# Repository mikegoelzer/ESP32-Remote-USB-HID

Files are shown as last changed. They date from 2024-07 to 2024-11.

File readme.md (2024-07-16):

# USB HID Keyboard over Wifi

<p align="center">
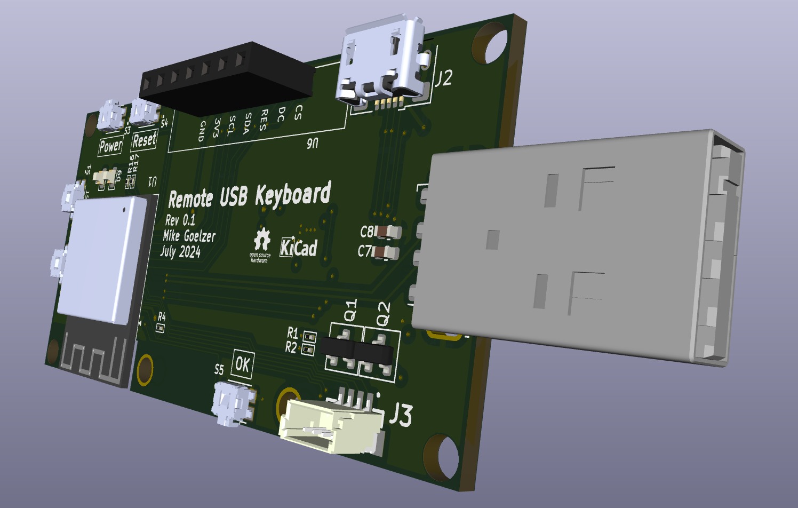
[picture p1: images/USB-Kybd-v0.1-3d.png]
USB HID Keyboard PCB 3D render
  
</p>

This project is the hardware and firmware for an ESP32-based remote USB keyboard. It's a dongle that plugs into a USB port on a computer and sends keystrokes that it receives over Wifi.  The connector `J3` also allows for wiring up to the PC motherboard's `F_PANEL` control pins, allowing for remote on/off and remote reboot.  

If you run a JST 4-conductor wire to `F_PANEL` there is a small adapter PCB that plugs it into the motherboard connector.

<p align="center">
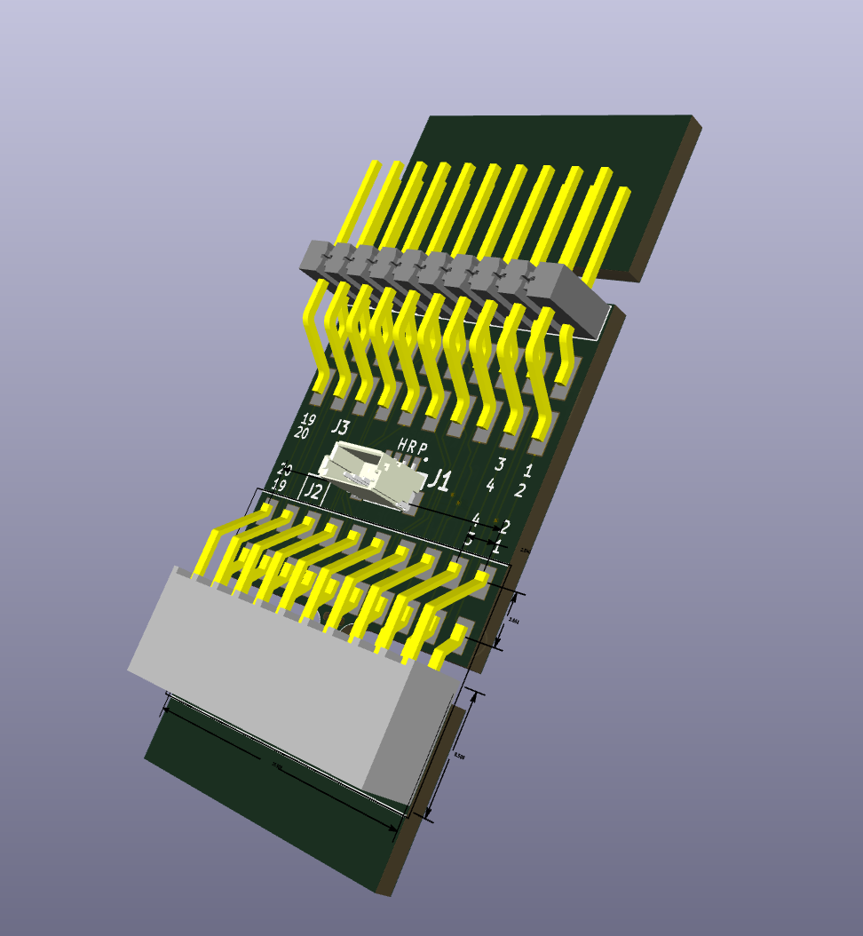
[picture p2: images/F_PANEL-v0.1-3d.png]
F_PANEL PCB 3D render
  
</p>

## Hardware

There are two Kicad projects, one for the USB key and one for the small adapter PCB:

  - USB keyboard PCB
    - [Schematic](Schematics/USBHIDKey.pdf)
    - [`USBHIDKey`](USBHIDKey/)
  - Adapter PCB
    - [Schematic](Schematics/F_PANEL_Shim.pdf)
    - [`F_PANEL_Adapter`](F_PANEL_Adapter/)

## Firmware

The firmware is in the [`esp32-firmware`](esp32-firmware/) directory. See its [README](esp32-firmware/usb-hid-kybd/README.md) for details.

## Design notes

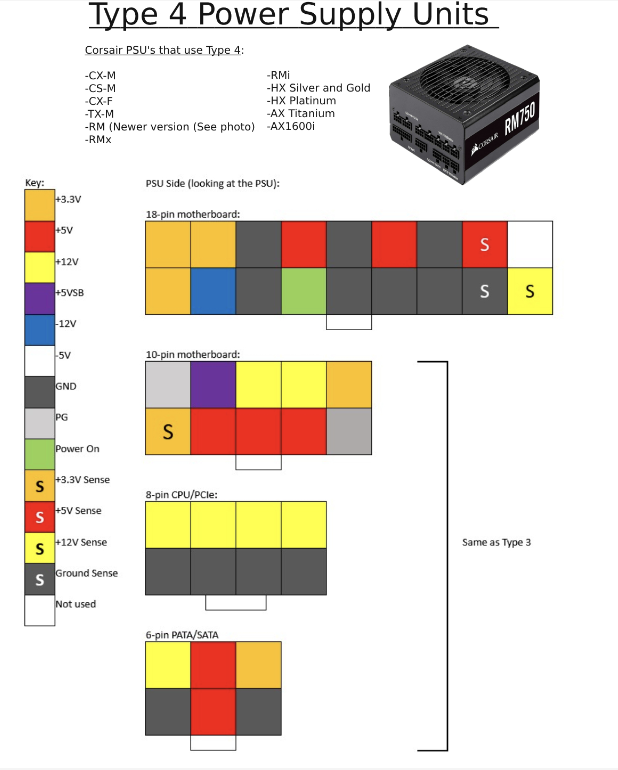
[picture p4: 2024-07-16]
References/RM1000e PSU/Corsair RM1000e Pinout.png

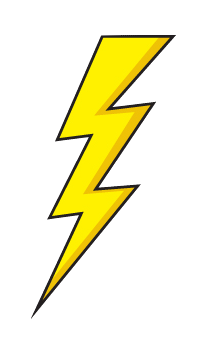
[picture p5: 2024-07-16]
images/lightning-bold.png

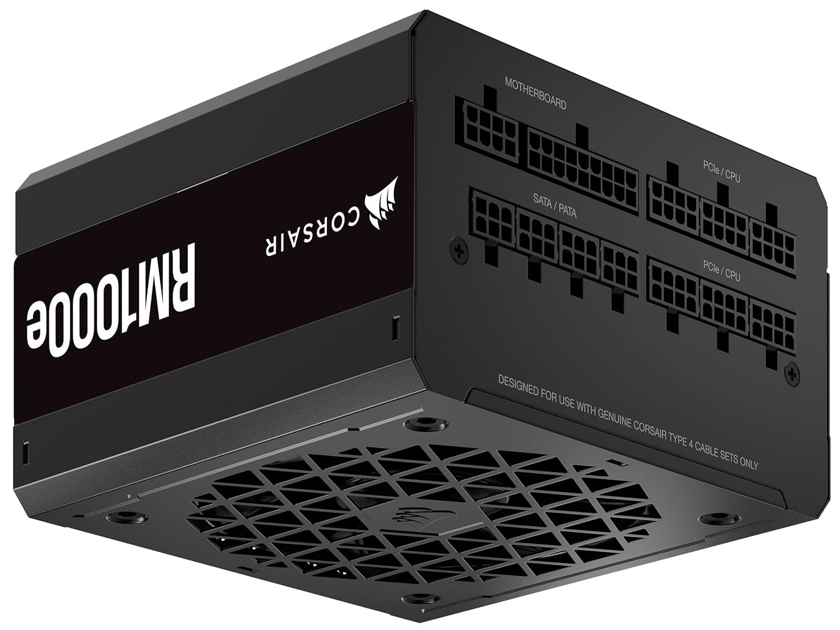
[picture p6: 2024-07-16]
References/RM1000e PSU/Corsair RM1000e Product Pic.jpg

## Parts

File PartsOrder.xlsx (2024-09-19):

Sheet: Sheet1
Desc | Part Ref | Actual Qty | Order Qty | Price | Subtotal | In basket? | Ordered? | Mfgr | MPN | Vendor URL | LCSC URL | Notes | Digikey | Adafruit | Mouser | Sparkfun
F_PANEL Shim | # of boards | 3
TSM-110-02-L-DH (2x10 RA male header 0.1") | J3 | 1 | 3 | 3.04 | $9.12 | ✅ | ❌ |  |  | https://www.digikey.com/en/products/detail/samtec-inc/TSM-110-02-L-DH/6692964 |  |  | 1
SMH-110-02-L-D (2x10 RA female receptacle 0.1") | J2 | 1 | 3 | 3.97 | $11.91 | ✅ | ❌ |  |  | https://www.digikey.com/en/products/detail/samtec-inc/SMH-110-02-L-D/6693507
PRT-17257 - 18" JST SH male-male cable |  | 1 | 1 | 2.38 | $2.38 | ✅ | ❌ |  |  | https://www.digikey.com/en/products/detail/sparkfun-electronics/PRT-17257/13629026
BM04B-SRSS-TB female vertical JST SH SMT receptacle | J1 | 1 | 3 | 0.62 | $1.86 | ✅ | ❌ |  |  | https://www.digikey.com/en/products/detail/jst-sales-america-inc/BM04B-SRSS-TB/926696
USB Dongle | # of boards | 3
CP2102N | U2 | 1 | 3 | 4.66 | $13.98 | - | - | Silicon Labs | CP2102N-A02-GQFN28 | https://www.digikey.com/en/products/detail/silicon-labs/CP2102N-A02-GQFN28/9863477 | https://www.lcsc.com/product-detail/USB-Converters_SKYWORKS-SILICON-LABS-CP2102N-A02-GQFN28_C1550553.html |  | 1
ESP32-S3-MINI-1-N8 | U1 | 1 | 3 | 3.10 | $9.30 | - | - | Expressif | ESP32-S3-MINI-1-N8 | https://www.digikey.com/en/products/detail/espressif-systems/ESP32-S3-MINI-1-N8/15295890 | https://www.lcsc.com/product-detail/WiFi-Modules_Espressif-Systems-ESP32-S3-MINI-1-N8_C2913206.html
MMBT4124LT1G (NPN BJT in SOT-23) | Q1,Q2 | 2 | 6 | 0.20 | $1.20 | - | - | onsemi | MMBT4124LT1G | https://www.digikey.com/en/products/detail/onsemi/MMBT4124LT1G/2705123
resistor 10k 1% 0201 | R1,R2,R9,R11 | 4 | 12 | 0.10 | $1.20 | - | - | YAGEO | RC0201FR-0710KL | https://www.digikey.com/en/products/detail/yageo/RC0201FR-0710KL/1948870
resistor 1k 1% 0201 | R3,R10,R12,R13,R16,R17 | 6 | 18 | 0.10 | $1.80 | - | - | YAGEO | RC0201FR-071KL | https://www.digikey.com/en/products/detail/yageo/RC0201FR-071KL/3202389
resistor 2k 1% 0201 | R4 | 1 | 3 | 0.10 | $0.30 | - | - | YAGEO | RC0201FR-072KL | https://www.digikey.com/en/products/detail/yageo/RC0201FR-072KL/3202400
resistor 22.1K 1% 0201 | R5 | 1 | 3 | 0.10 | $0.30 | - | - | Panasonic | ERJ-1GNF2212C | https://www.digikey.com/en/products/detail/panasonic-electronic-components/ERJ-1GNF2212C/2036263
resistor 47.5K 1% 0201 | R6 | 1 | 3 | 0.00 | $0.00 | - | - | Panasonic | ERJ-1GNF4752C | https://www.digikey.com/en/products/detail/panasonic-electronic-components/ERJ-1GNF4752C/2036303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
resistor 100k 1% 0201 | R8 | 1 | 3 | 0.10 | $0.30 | - | - | YAGEO | RC0201FR-07100KL | https://www.digikey.com/en/products/detail/yageo/RC0201FR-07100KL/1948859
resistor 453k 1% 0201 | R7 | 1 | 3 | 0.10 | $0.30 | - | - | YAGEO | RC0201FR-07453KL | https://www.digikey.com/en/products/detail/yageo/RC0201FR-07453KL/5280540
cap X7R 10uF/16V (10%) 0603 | C1, C3, C4, C5, C7 | 5 | 15 | 0.33 | $4.95 | - | - | MuRata | GRM188Z71A106KA73D | https://www.digikey.com/en/products/detail/murata-electronics/GRM188Z71A106KA73D/13401725 |  |  | 1
cap X7R 0.1uF/100V (10%) 0603 | C2, C8 | 2 | 6 | 0.21 | $1.26 | - | - | MuRata | GRM188R72A104KA35D | https://www.digikey.com/en/products/detail/murata-electronics/GRM188R72A104KA35D/702549 |  |  | 1
CAP CER 120PF 25V X7R 0201 | C6 | 1 | 3 | 0.10 | $0.30 | - | - | MuRata | GRM033R71E121KA01D | https://www.digikey.com/en/products/detail/murata-electronics/GRM033R71E121KA01D/702439
TPD2EUSB30A bidir D+/D- TVs in TI DRT-3 (SOT-23-3) | U3,U4 | 2 | 6 | 0.48 | $2.88 | - | - | TI | TPD2EUSB30ADRTR | https://www.digikey.com/en/products/detail/texas-instruments/tpd2eusb30adrtr/2520830 |  |  | 1
ESD5Z5.0T1G TVS diode, undirectional, in SOD-523 | D1,D2 | 2 | 6 | 0.24 | $1.44 | - | - | onsemi | ESD5Z5.0T1G | https://www.digikey.com/en/products/detail/onsemi/ESD5Z5-0T1G/1476609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 |  |  | 1
BAT60A Schottky 3A/10V in SOD-323 | D3,D4 | 2 | 6 | 0.44 | $2.64 | - | - | Infineon | BAT60AE6327HTSA1 | https://www.digikey.com/en/products/detail/infineon-technologies/BAT60AE6327HTSA1/1280934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 |  |  | 1
Amphenol 10118193-0001 USB Micro B R/A conn SMT | J2 | 1 | 3 | 0.46 | $1.38 | - | - | Amphenol | 10118193-0001LF | https://www.digikey.com/en/products/detail/amphenol-cs-fci/10118193-0001LF/2785388 |  |  | 1
Molex USB-A plug male SMT | J1 | 1 | 3 | 1.45 | $4.35 | - | - | Molex | 480372200 | https://www.digikey.com/en/products/detail/molex/0480372200/2421361
TPS62823 3A buck | U5 | 1 | 3 | 1.93 | $5.79 | - | - | Texas Instruments | TPS62823DLCT | https://www.digikey.com/en/products/detail/texas-instruments/TPS62823DLCT/9554624
470nF inductor | L1 | 1 | 3 | 0.32 | $0.96 | - | - | MuRata | DFE201610E-R47M=P2 | https://www.digikey.com/en/products/detail/murata-electronics/DFE201610E-R47M-P2/7927536
N-channel enhancement mode MOSFET BSH111 | Q3 | 1 | 3 | 0.26 | $0.78 | - | - | Nexperia | BSH111BKR | https://www.digikey.com/en/products/detail/nexperia-usa-inc/BSH111BKR/5423826
Green LED 0603 | D5,D7,D8 | 3 | 9 | 0.15 | $1.35 | - | - | Wurth | 150060VS75000 | https://www.digikey.com/en/products/detail/w%C3%BCrth-elektronik/150060VS75000/4489906
Blue LED 0603 |  | 1 | 3 | 0.16 | $0.48 | - | - | Wurth | 150060BS75000 | https://www.digikey.com/en/products/detail/w%C3%BCrth-elektronik/150060BS75000/4489895
Amber LED 0603 | D6,D9 | 2 | 6 | 0.15 | $0.90 | - | - | Wurth | 150060AS75000 | https://www.digikey.com/en/products/detail/w%C3%BCrth-elektronik/150060AS75000/10468254
Red LED 0603 |  |  | 0 | 0.15 | $0.00 | - | - | Wurth | 150060SS75000 | https://www.digikey.com/en/products/detail/w%C3%BCrth-elektronik/150060SS75000/4489903
JST SH series vertical receptacle BM04B | J3 | 1 | 3 | 0.62 | $1.86 | - | - | JST | BM04B-SRSS-TB | https://www.digikey.com/en/products/detail/jst-sales-america-inc/BM04B-SRSS-TB/926696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
HiLetGo 0.95" SPI OLED | U6 | 1 | 3 | 12.99 | $38.97 | ❌ | ❌ | HiLetGo | N/A | https://www.amazon.com/dp/B0711RKXB5?psc=1&ref=ppx_yo2ov_dt_b_product_details
Right angle SMT tactile button | S1,S2,S3,S4,S5 | 4 | 12 | 0.30 | $3.60 | - | - | Panasonic | EVQ-P7L01P | https://www.digikey.com/en/products/detail/panasonic-electronic-components/EVQ-P7L01P/4429453
CONN HDR 7POS 0.1 TIN PCB | U6 | 1 | 3 | 0.60 | $1.80 | ✅ | ❌ | Sullins | PPTC071LFBN-RC | https://www.digikey.com/en/products/detail/sullins-connector-solutions/PPTC071LFBN-RC/810146
Wire
28 AWG wire
PAD-11 crimp tool
22 guage wire (for breadboard, not req'd here)
heat shrink tubing - 24 in?

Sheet: 7Aeg 4Digit Board
Desc | Parts | Actual Qty | Order Qty | Price | Subtotal | In basket? | Ordered? | Vendor URL | Notes
7-Segment Board (4 digit)
# of boards | 2
2-digit common cathod 7-segment (red) | U1 | 1 | 2 | $3.29 | $6.58 | ❌ | ❌ | https://www.mouser.com/ProductDetail/Kingbright/DC56-11GWA?qs=sXafwHSx%252BU%252BFqc2jozM64A%3D%3D
2-digit common cathod 7-segment (green) | U2 | 1 | 2 | $3.29 | $6.58 | ❌ | ❌ | https://www.mouser.com/ProductDetail/Kingbright/DC56-11EWA?qs=SO8VdE%2FgosGvL%2FnJcFkMow%3D%3D
560 ohm resistors, 1206 | R1-R8 | 8 | 16 | 0.29 | $4.64 | ❌ | ❌ | https://www.mouser.com/ProductDetail/Vishay-Dale/RCC1206560RFKEA
1k resistors, 1206 | OMIT | 0 | 0 | 0.29 | $0.00 | ❌ | ❌ | https://www.mouser.com/ProductDetail/Vishay-Dale/RCC12061K00FKEA?qs=IS%252B4QmGtzzoI2b9zl4DztQ%3D%3D
74AC139SCX demultiplexer | U3 | 1 | 2 | 0.78 | $1.56 | ❌ | ❌ | https://www.mouser.com/ProductDetail/onsemi-Fairchild/74AC139SCX?qs=3nN3J2YzXAFlT5ge091P%252BA%3D%3D | Need 74AC to work at my voltages, not ACT
2.54 1x07 breakaway male pins | N/A | 0 | 0 | 0.46 | $0.00 | ❌ | ❌ | https://www.mouser.com/ProductDetail/Molex/22-28-4071?qs=GAPJcf4kvdu8z4oUFowNtQ%3D%3D
2.54 1x07 breakaway male pins | N/A | 2 | 4 | 0.46 | $1.84 | ❌ | ❌ | https://www.mouser.com/ProductDetail/Molex/22-28-4071?qs=GAPJcf4kvdu8z4oUFowNtQ%3D%3D
0.1uF ceramic 1206 50V X7R | C1 | 1 | 2 | 0.11 | $0.22 | ❌ | ❌ | https://www.mouser.com/ProductDetail/KEMET/C1206C104K5RAC7867?qs=r%2FVmNO8Tjq5MvP%2FjoJQjcw%3D%3D
10uF ceramic 1206 | C2 | 1 | 2 | 0.3 | $0.60 | ❌ | ❌ | https://www.mouser.com/ProductDetail/KEMET/C1206C106K4PACTU?qs=nz7vn1PXJ%2Feyzlyip0aTxw%3D%3D
Alternative to 560 ohm resistors: 820 ohm 1206 |  |  |  | 0.1 |  |  |  | https://www.digikey.com/en/products/detail/yageo/RC1206JR-07820RL/729342

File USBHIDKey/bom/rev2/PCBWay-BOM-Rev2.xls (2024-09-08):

PCBWay Bom
Item # | *Designator | *Qty | Manufacturer | *Mfg Part # | Description / Value | *Package/Footprint | Mounting Type | Your Instructions / Notes
1 | U1 | 1 | Expressif | ESP32-S3-MINI-1-N8 | RF TXRX MOD BT WIFI PCB TH SMD | 41-SMD Module | SMD
2 | U2 | 1 | Silicon Labs | CP2102N-A02-GQFN28 | IC USB TO UART BRIDGE QFN28 | QFN28 | SMD
3 | Q1,Q2 | 2 | onsemi | MMBT4124LT1G | TRANS NPN 25V 0.2A SOT23-3 | SOT-23-3 | SMD | OK to substitute with L8050QLT1G
4 | U3,U4 | 2 | Texas Instruments | TPD2EUSB30ADRTR | TVS DIODE 3.6VWM 8VC SOT9X3 | DRT-3 (SOT-23-3) | SMD
5 | D3,D4 | 2 | onsemi | ESD5Z5.0T1G | TVS DIODE 5VWM 18.6VC SOD523 | SOD-523 | SMD | Ok to substitute with LESD5D5.0CT1G
6 | D1,D2 | 2 | Infineon | BAT60AE6327HTSA1 | DIODE SCHOTTKY 10V 3A SOD323-2 | SOD-323 | SMD
7 | J2 | 1 | Amphenol | 10118193-0001LF | CONN RCPT USB2.0 MICRO B SMD R/A | SMT USB Micro-B R/A | SMD
8 | J1 | 1 | Molex | 480372200 | CONN PLUG USB2.0 TYPEA 4P SMD RA | SMT USB Micro-A Plug Male | SMD
9 | R1,R2,R9,R11 | 4 | YAGEO | RC0201FR-0710KL | RES 10K OHM 1% 0201 | 0201 | SMD | OK any 10k 1% 0201 resistor
10 | R3,R10,R16,R17 | 4 | YAGEO | RC0201FR-071KL | RES 1K OHM 1% 0201 | 0201 | SMD | OK any 1k 1% 0201 resistor
11 | R4 | 1 | YAGEO | RC0201FR-072KL | RES 2K OHM 1% 0201 | 0201 | SMD | OK any 2k 1% 0201 resistor
12 | R5 | 1 | YAGEO | RC0201FR-0722K1L | RES 22.1K OHM 1% 0201 | 0201 | SMD | OK any 22.1k 1% 0201 resistor
13 | R6 | 1 | YAGEO | AC0201FR-0747K5L | RES 47.5K OHM 1% 0201 | 0201 | SMD | OK any 47.5k 1% 0201 resistor
14 | C1, C3, C4, C5, C7 | 5 | Murata | GRM188Z71A106KA73D | CAP CER 10UF 10V X7R 0603 | 0603 | SMD
15 | C2, C8 | 2 | Murata | GRM188R72A104KA35D | CAP CER 0.1UF 100V X7R 0603 | 0603 | SMD
16 | U5 | 1 | Texas Instruments | TPS62823DLCT | IC REG BUCK ADJ 3A 8VSON | VSON-HR-8 | SMD
17 | L1 | 1 | Murata | DFE201610E-R47M=P2 | FIXED IND 470NH 3.6A 32 MOHM SMD | SMT (Custom footprint) | SMD
18 | C6 | 1 | Murata | GRM033R71E121KA01D | CAP CER 120PF 25V X7R 0201 | 0201 | SMD
19 | R7 | 1 | YAGEO | RC0201FR-07453KL | RES 453K OHM 1% 0201 | 0201 | SMD | OK any 453k 1% 0201 resistor
20 | R8 | 1 | YAGEO | RC0201FR-07100KL | RES 100K OHM 1% 0201 | 0201 | SMD | OK any 100k 1% 0201 resistor
21 | Q3 | 1 | Nexperia | BSH111BKR | MOSFET N-CH 55V 210MA TO236AB | TO-236AB (SOT-23) | SMD
22 | D5,D7,D8 | 3 | Wurth | 150060VS75000 | LED GREEN CLEAR 0603 SMD | 0603 | SMD
23 | D6, D9 | 2 | Wurth | 150060AS75000 | LED AMBER CLEAR 0603 SMD | 0603 | SMD
24 | J3 | 1 | JST | BM04B-SRSS-TB | CONN HEADER SMD 4POS 1MM | SMT (Custom footprint) | SMD
25 | U6 | 0 | N/A | N/A | N/A | DNP | DNP | DNP - just drill and plate the holes
26 | S1,S2,S3,S4,S5 | 5 | Panasonic | EVQ-P7L01P | SWITCH TACTILE SPST-NO 0.05A 12V | SMT (Custom footprint) | SMD
27 | R12,R13 | 2 | YAGEO | RC0201FR-07330KL | RES 330 OHM 1% 0201 | 0201 | SMD | OK any 1k 1% 0201 resistor

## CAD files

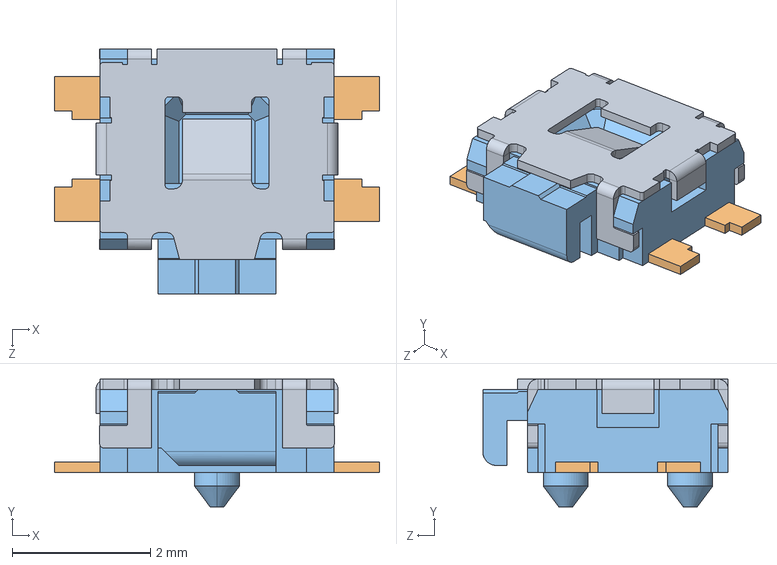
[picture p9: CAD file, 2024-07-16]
Parts/EVQ-P7L01P/EVQ-P7L01P.step
4.70 x 1.85 x 3.55 mm

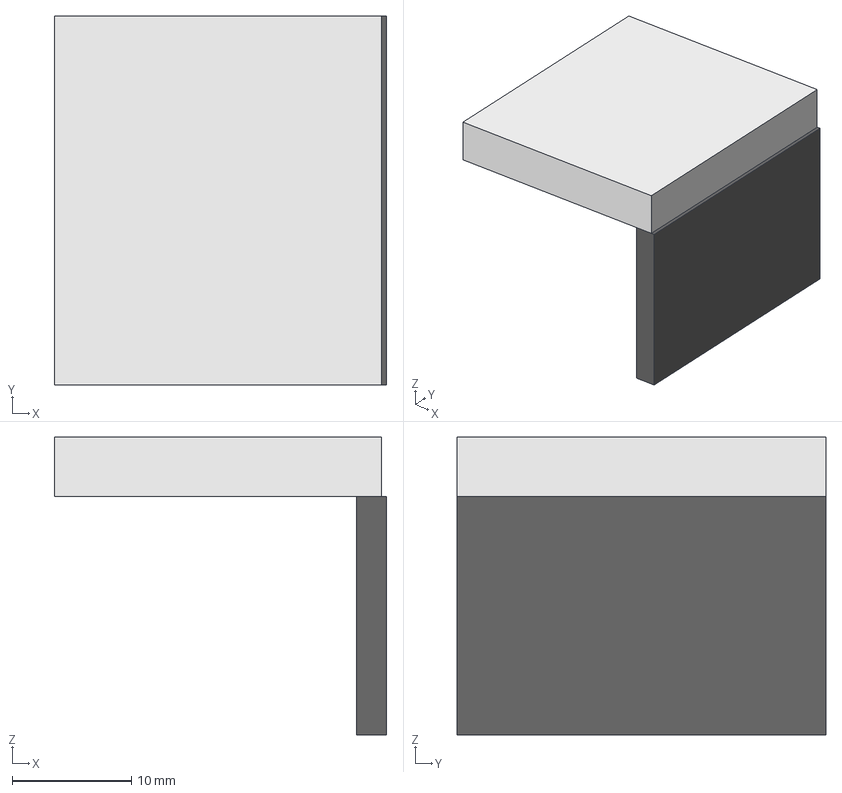
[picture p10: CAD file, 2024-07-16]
Parts/HiLetGo 0.95in OLED SSD1331 SPI/Handmade 3D Model/oled.stp
27.9 x 31.0 x 25.0 mm
Sketch
Sketch001

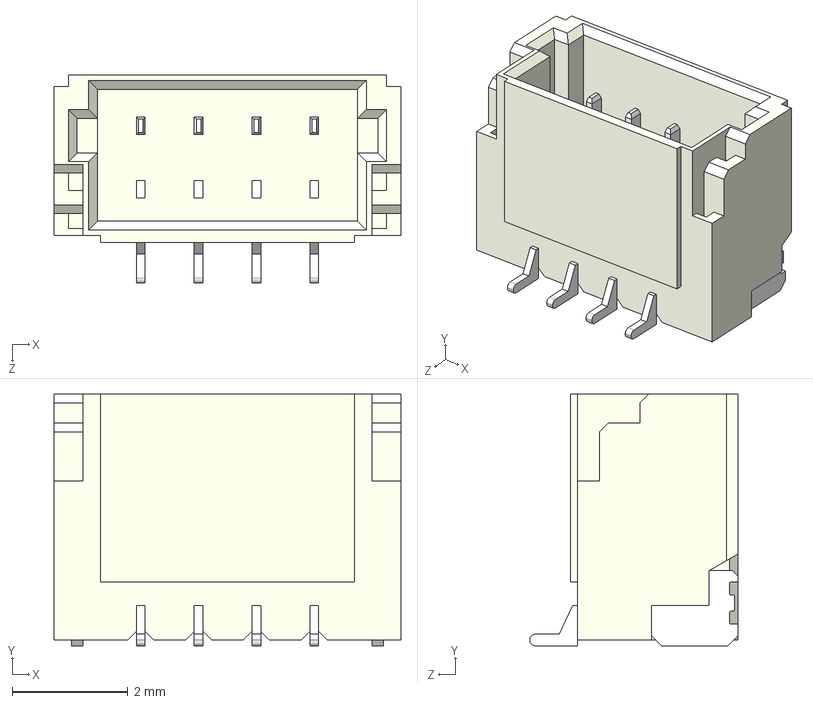
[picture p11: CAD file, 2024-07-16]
Parts/JST SH Series Receptacle Vertical - BM04B-SRSS-TB_LF_SN/BM04B-SRSS-TB_LF__SN_/3D/BM04B-SRSS-TB_LF__SN_.stp
6.00 x 4.35 x 3.60 mm
BM04B-SRSS-TB(LF)(SN)-PIN
BM04B-SRSS-TB(LF)(SN)-BODY

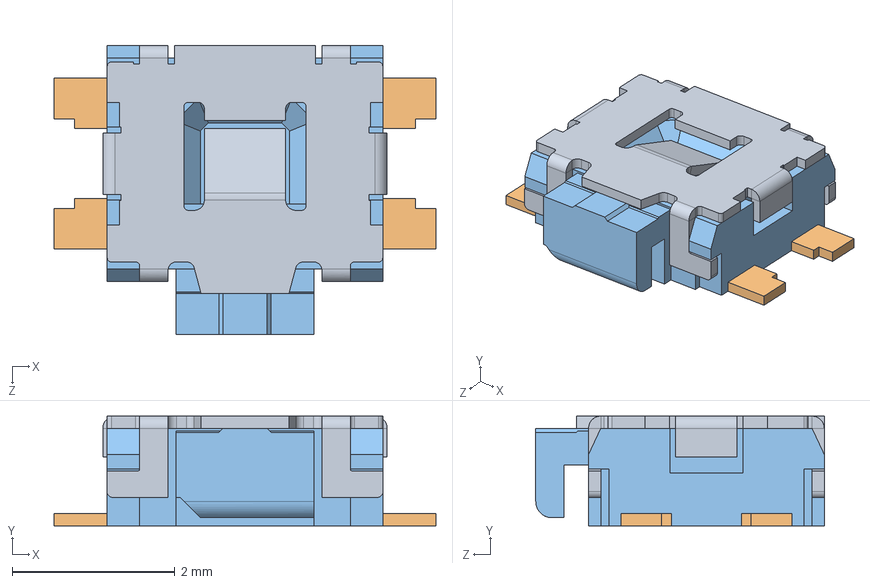
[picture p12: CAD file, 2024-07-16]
Parts/Panasonic RA Button - EVQ-P7A01P/EVQ-P7A01P.step
4.70 x 1.35 x 3.55 mm

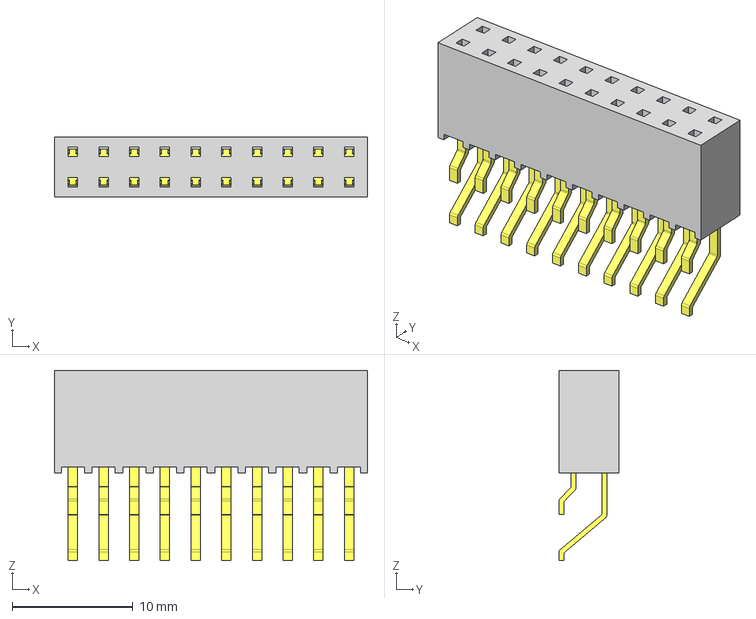
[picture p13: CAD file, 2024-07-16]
Parts/Samtec 2x10 SMT Female RA - SMH_110_02_L_D/SAMTEC-SMH-110-02-X-D.step
25.9 x 4.95 x 15.7 mm
SMH-110-D_socket
C-08-03-10-D_SMH

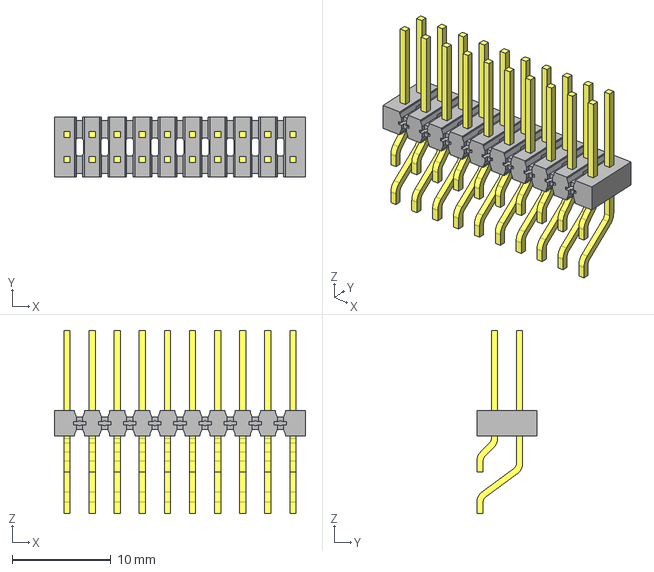
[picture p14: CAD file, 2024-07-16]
Parts/Samtec 2x10 SMT Male RA - TSM_110_02_L_DH/TSM-110-02-L-DH.step
25.4 x 6.10 x 18.5 mm
TSM-110-02-DH_body
T-1S6-09(-02-10-DH)

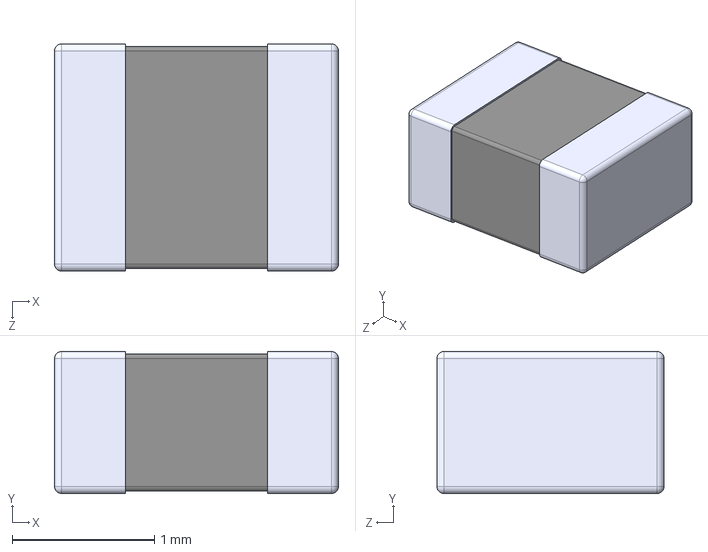
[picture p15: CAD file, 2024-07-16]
Parts/DFE201610E_R47M_P2/DFE201610E-R47M_P2.step
2.00 x 1.00 x 1.60 mm

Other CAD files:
Parts/HiLetGo 0.95in OLED SSD1331 SPI/Handmade 3D Model/oled.FCStd
Parts/JST SH Series Receptacle Vertical - BM04B-SRSS-TB_LF_SN/BM04B-SRSS-TB_LF__SN_/Allegro/bm04b-srss-tb_lfsn_.psm
Parts/JST SH Series Receptacle Vertical - BM04B-SRSS-TB_LF_SN/BM04B-SRSS-TB_LF__SN_/DEHDL/bm04b_srss_tb_lf__sn_/chips/chips.prt

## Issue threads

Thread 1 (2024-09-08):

3.3V regulator feedback resistors reversed

mikegoelzer, 2024-09-08:
- The top and bottom feedback resistors were reversed on the first rev of the PCB.
 - This is causing voltage regulator to output stable 0.735V instead of 3.3V 😭
 - Fix is to swap the two resistors

<div align="center">
  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
</div>

mikegoelzer, 2024-09-08:
Calcs in [tps62823 calcs.xls](https://github.com/mikegoelzer/ESP32-Remote-USB-HID/blob/main/Notes/tps62823%20calcs.xls) spreadsheet

Closed 2024-09-08.

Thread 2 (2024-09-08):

Add connector for screen image capture

mikegoelzer, 2024-09-08:
An improvement would be if either:
 - a second small board intercepted the HDMI output, transformed it to a JPEG, and fed that JPEG into this board so that ESP32 could transmit it over Wifi
 - an OV2650 connector allowed a physical camera to capture what's in the screen.  image quality will be poor, but probably good enough, and doesn't require a second FPGA circuit that intercepts HDMI signals

Either of these requires some additional connector on the PCB that is wired into the ESP32 (SPI in the first option, standard ESP32 camera input in second option).

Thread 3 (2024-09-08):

D6/D7 land pads should be 0603

mikegoelzer, 2024-09-08:
Currently, D6/D7 land pads are 0201.  However, parts in BOM spreadsheet are 0603 LEDs.

Solution:
 - [ ] change PCB layout to accommodate 0603 LEDs in D6/D7 positions
 - [ ] remove comments from `T-2C2W538179A-2sets-PCBWay-BOM(2024-07-18) - CORRECTED` and keep part numbers as-is

Closed 2024-09-08.

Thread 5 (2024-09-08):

BOM spreadsheet designators reversed on D1/D2 <-> D3/D4

mikegoelzer, 2024-09-08:
Error BOM spreadsheet:
 - The spreadsheet reversed the designators D1/D2 (which should be BAT60AE6327HTSA1) and D3/D4 (which should be ESD5Z5.0T1G)
 - Just reverse the designators in the spreadsheet, change nothing in the kicad files, and error is corrected.

Closed 2024-09-08.

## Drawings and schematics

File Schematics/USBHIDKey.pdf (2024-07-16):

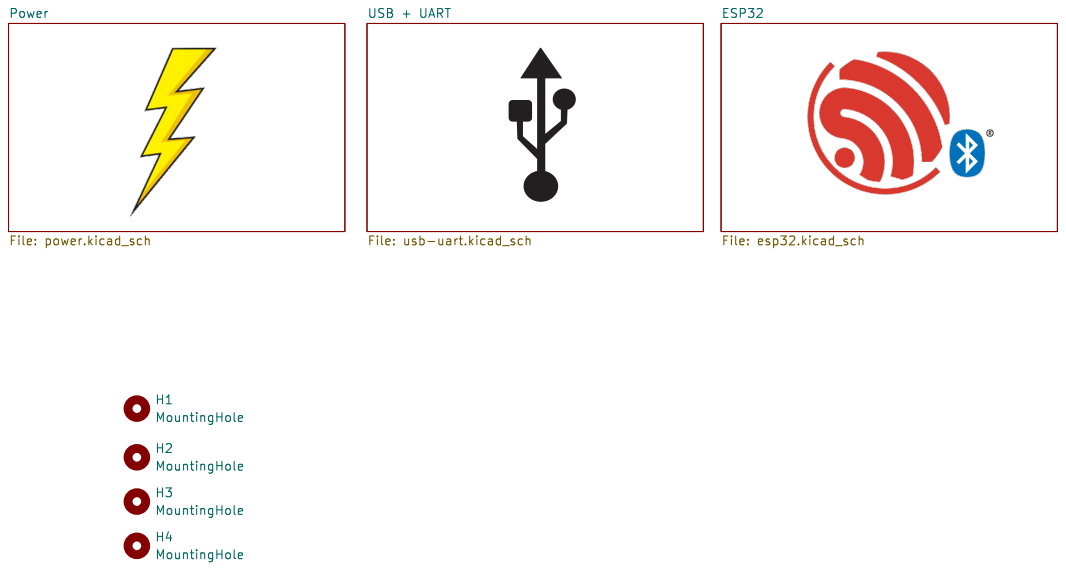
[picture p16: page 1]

Id: 1/4 Title: File: USBHIDKey.kicad_sch Sheet: /

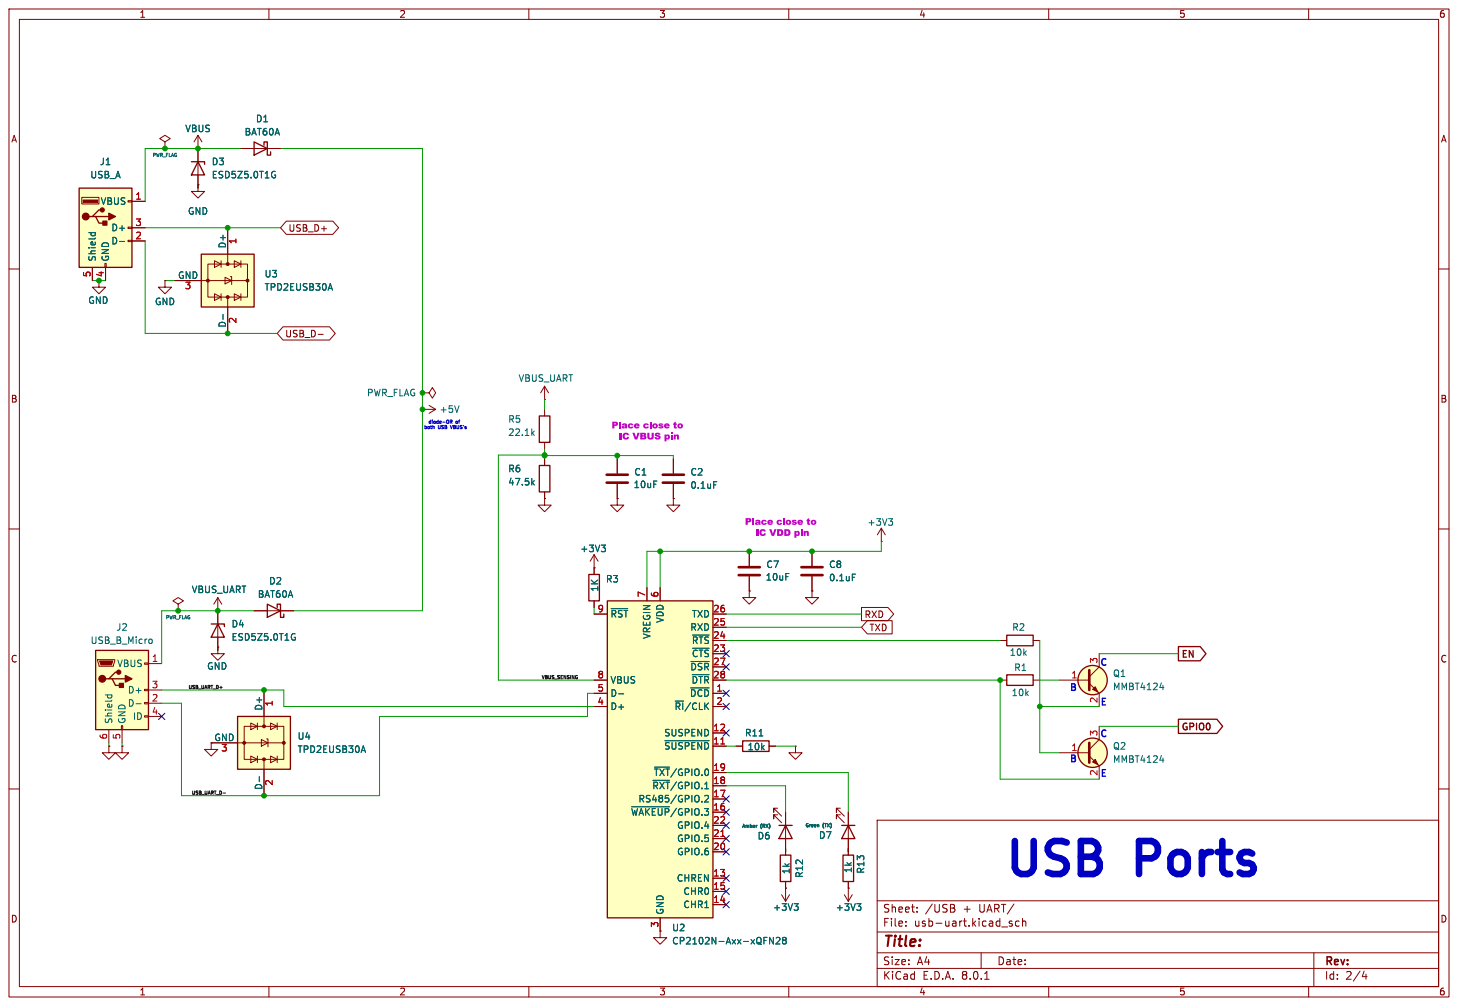
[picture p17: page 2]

IC VDD pin Place close to
IC VBUS pin
Amber (RX) C2

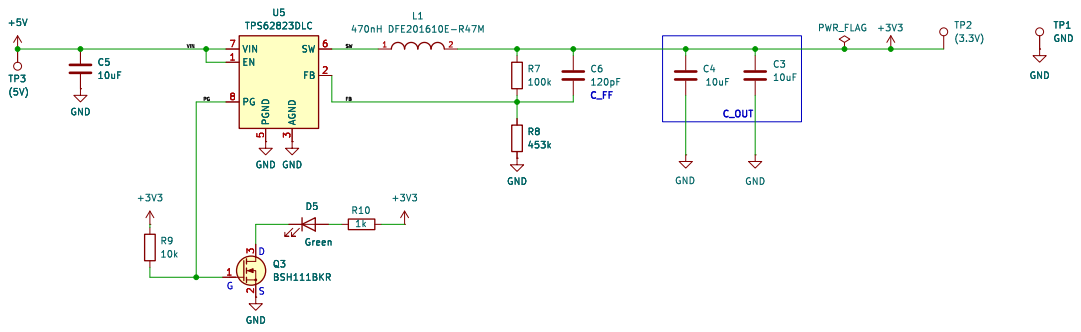
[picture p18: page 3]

5 SW 6 VIN 7 PG 8 U5 TPS62823DLC GND

5 SW 6 VIN 7 PG 8 GND

Id: 3/4 Title: File: power.kicad_sch Sheet: /Power/

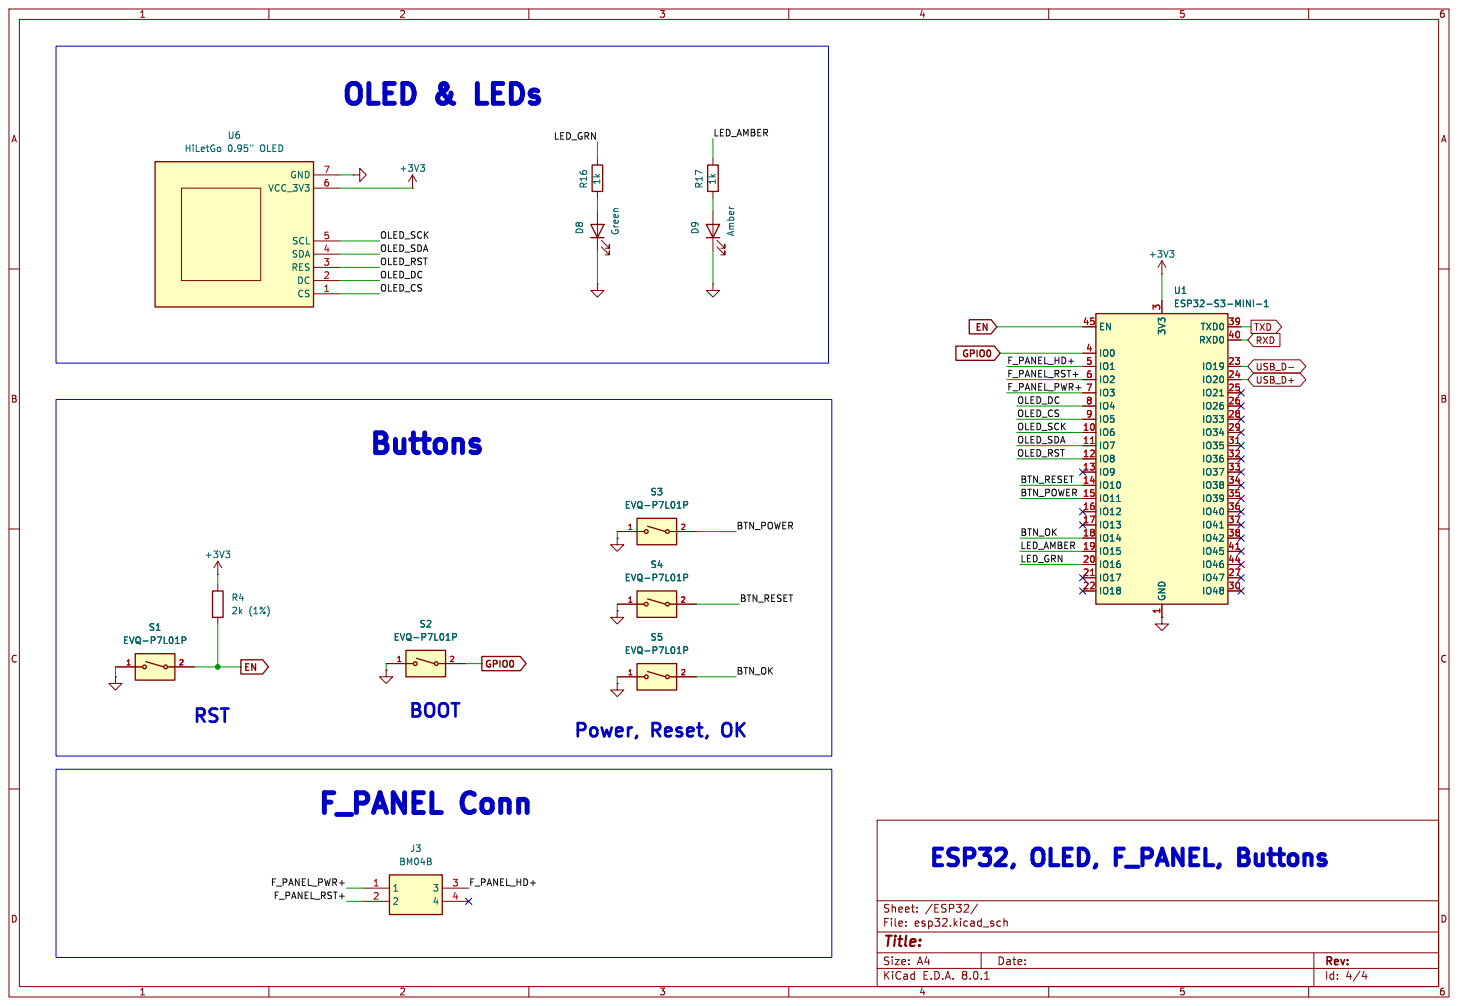
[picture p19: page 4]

Id: 4/4 Title: File: esp32.kicad_sch Sheet: /ESP32/

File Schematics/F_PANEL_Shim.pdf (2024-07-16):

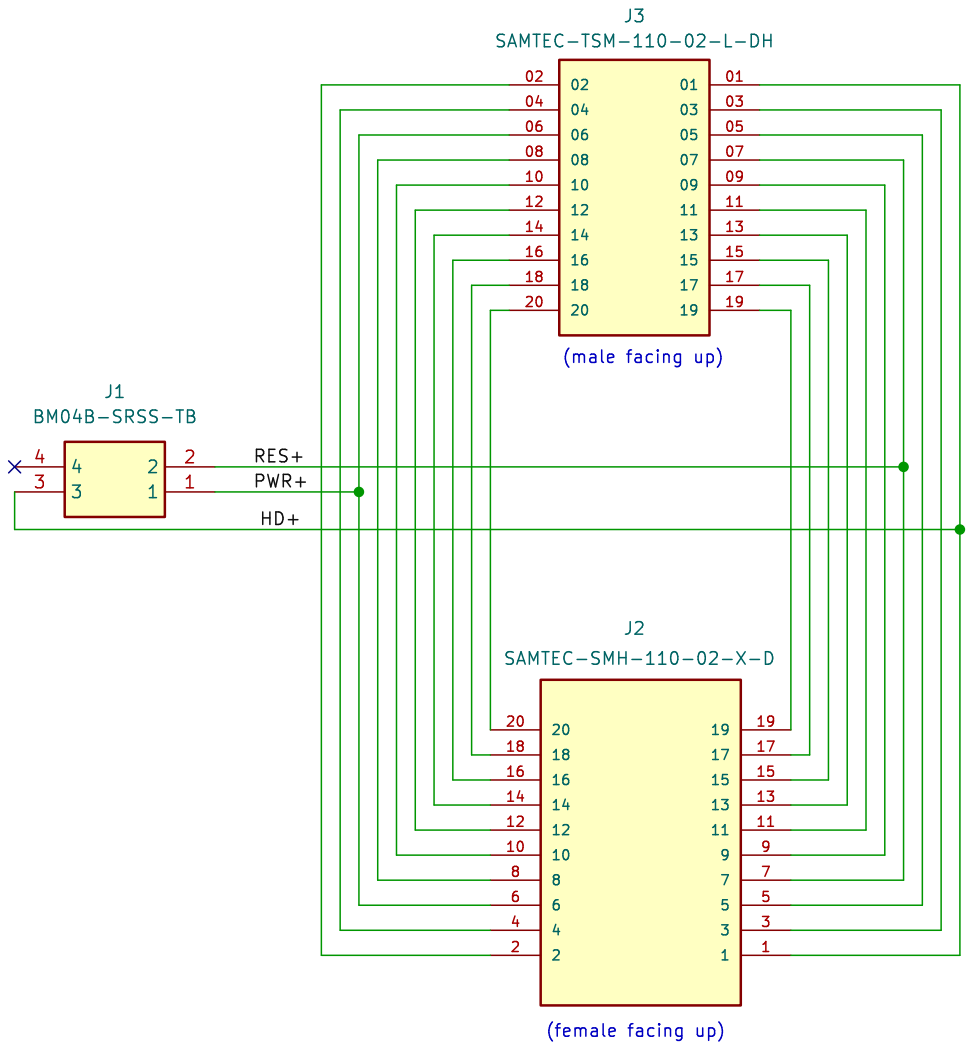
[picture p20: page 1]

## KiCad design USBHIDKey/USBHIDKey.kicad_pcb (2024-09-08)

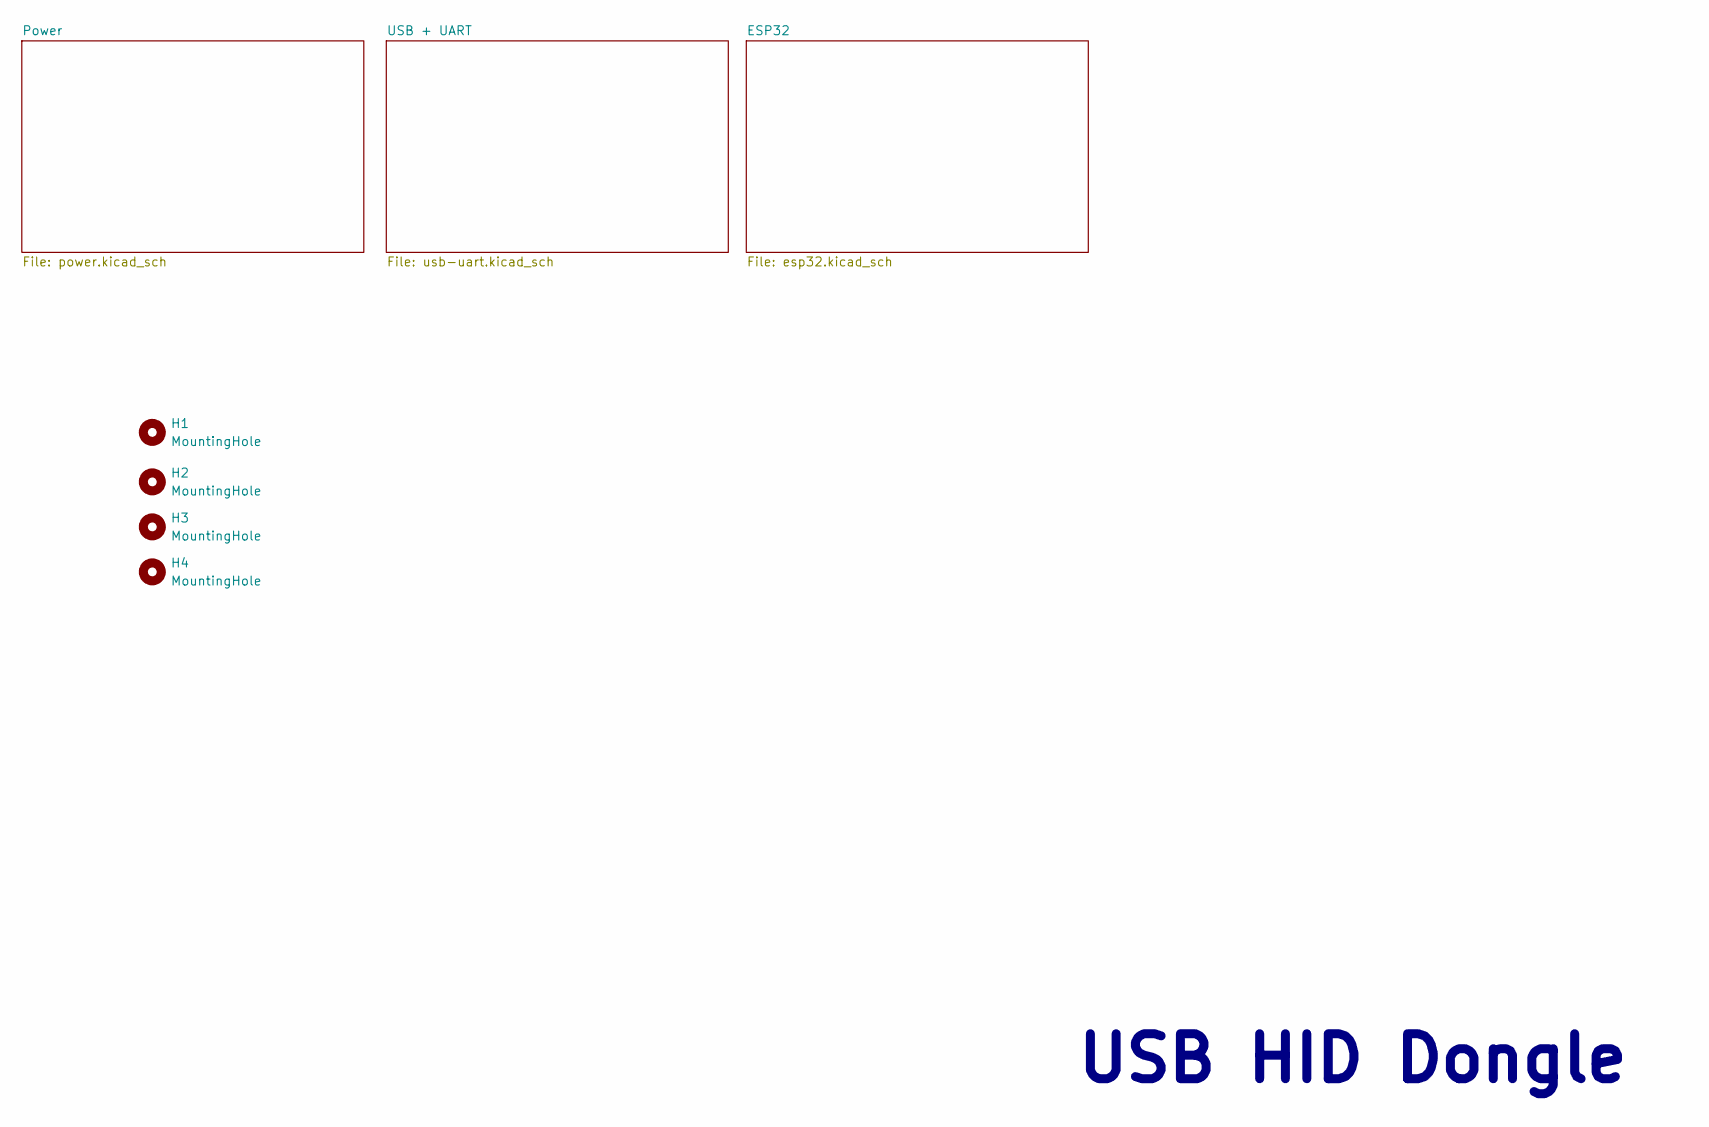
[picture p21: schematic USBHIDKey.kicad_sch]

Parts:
H1, H2, H3, H4: MountingHole; MountingHole_3mm

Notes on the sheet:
USB HID Dongle

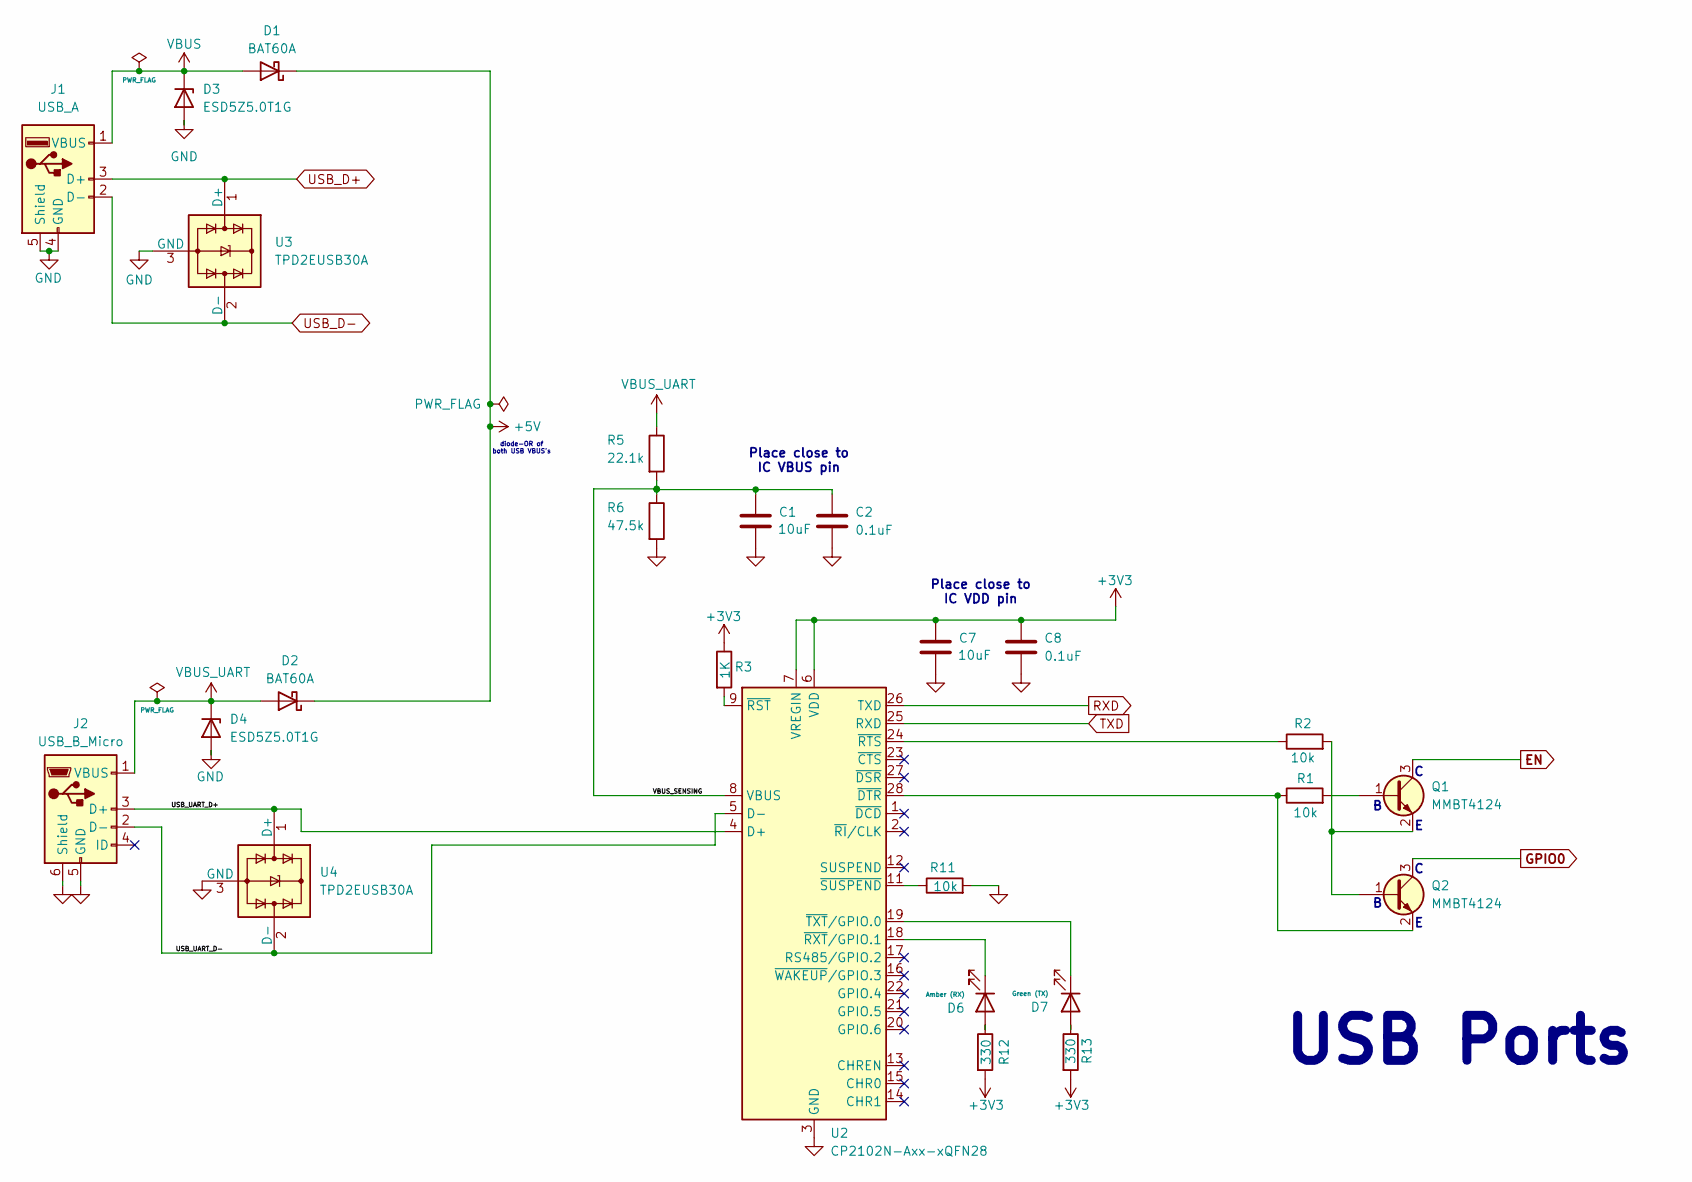
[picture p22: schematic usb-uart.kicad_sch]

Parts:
C1, C7: 10uF; C_0603_1608Metric; MPN GRM188Z71A106KA73D
C2, C8: 0.1uF; C_0603_1608Metric; MPN GRM188R72A104KA35D
D1, D2: BAT60A; D_SOD-323; MPN BAT60AE6327HTSA1
D3, D4: ESD5Z5.0T1G; D_SOD-523; MPN ESD5Z5.0T1G
D6: Amber (RX); LED_0603_1608Metric; MPN 150060AS75000
D7: Green (TX); LED_0603_1608Metric; MPN 150060VS75000
J1: USB_A; USB_A_Molex_48037-2200_Horizontal; MPN 0480372200
J2: USB_B_Micro; USB_Micro-B_Amphenol_10118193-0001LF_Horizontal; MPN 10118193-0001LF
Q1, Q2: MMBT4124; SOT-23; MPN MMBT4124LT1G
R1, R2, R11: 10k; R_0201_0603Metric; MPN RC0201FR-0710KL
R3: 1K; R_0201_0603Metric; MPN RC0201FR-071KL
R5: 22.1k; R_0201_0603Metric; MPN ERJ-1GNF2212C
R6: 47.5k; R_0201_0603Metric; MPN ERJ-1GNF4752C
R12, R13: 330; R_0201_0603Metric; MPN RC0201FR-07330KL
U2: CP2102N-Axx-xQFN28; QFN-28-1EP_5x5mm_P0.5mm_EP3.35x3.35mm; MPN CP2102N-A02-GQFN28
U3, U4: TPD2EUSB30A; Texas_DRT-3; MPN TPD2EUSB30ADRTR

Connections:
+3V3: C7.1, C8.1, R3.1, R12.2, R13.2, U2.6 (VDD), U2.7 (VREGIN); also elsewhere on the board
+5V: D1.1 (K), D2.1 (K); also elsewhere on the board
/USB + UART/USB_UART_D+: J2.3 (D+), U2.4 (D+), U4.1 (D+)
/USB + UART/USB_UART_D-: J2.2 (D-), U2.5 (D-), U4.2 (D-)
/USB + UART/VBUS_SENSING: C1.1, C2.1, R5.2, R6.1, U2.8 (VBUS)
EN: Q1.3 (C); also elsewhere on the board
GND: C1.2, C2.2, C7.2, C8.2, D3.2 (A), D4.2 (A), J1.4 (GND), J1.5 (Shield), J2.5 (GND), J2.6 (Shield), R6.2, R11.2, U2.3 (GND), U2.29 (GND), U3.3 (GND), U4.3 (GND); also elsewhere on the board
GPIO0: Q2.3 (C); also elsewhere on the board
unnamed: D6.2 (A), R12.1
unnamed: D6.1 (K), U2.18 (~RXT/GPIO.1)
unnamed: D7.2 (A), R13.1
unnamed: D7.1 (K), U2.19 (~TXT/GPIO.0)
unnamed: Q1.1 (B), R1.2
unnamed: Q1.2 (E), Q2.1 (B), R2.2
unnamed: Q2.2 (E), R1.1, U2.28 (~DTR)
unnamed: R3.2, U2.9 (~RST)
unnamed: R2.1, U2.24 (~RTS)
unnamed: R11.1, U2.11 (~SUSPEND)
RXD: U2.26 (TXD); also elsewhere on the board
TXD: U2.25 (RXD); also elsewhere on the board
USB_D+: J1.3 (D+), U3.1 (D+); also elsewhere on the board
USB_D-: J1.2 (D-), U3.2 (D-); also elsewhere on the board
VBUS: D1.2 (A), D3.1 (K), J1.1 (VBUS)
VBUS_UART: D2.2 (A), D4.1 (K), J2.1 (VBUS), R5.1

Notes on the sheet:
Place close to IC VDD pin
diode-OR of both USB VBUS's
Place close to IC VBUS pin
USB Ports

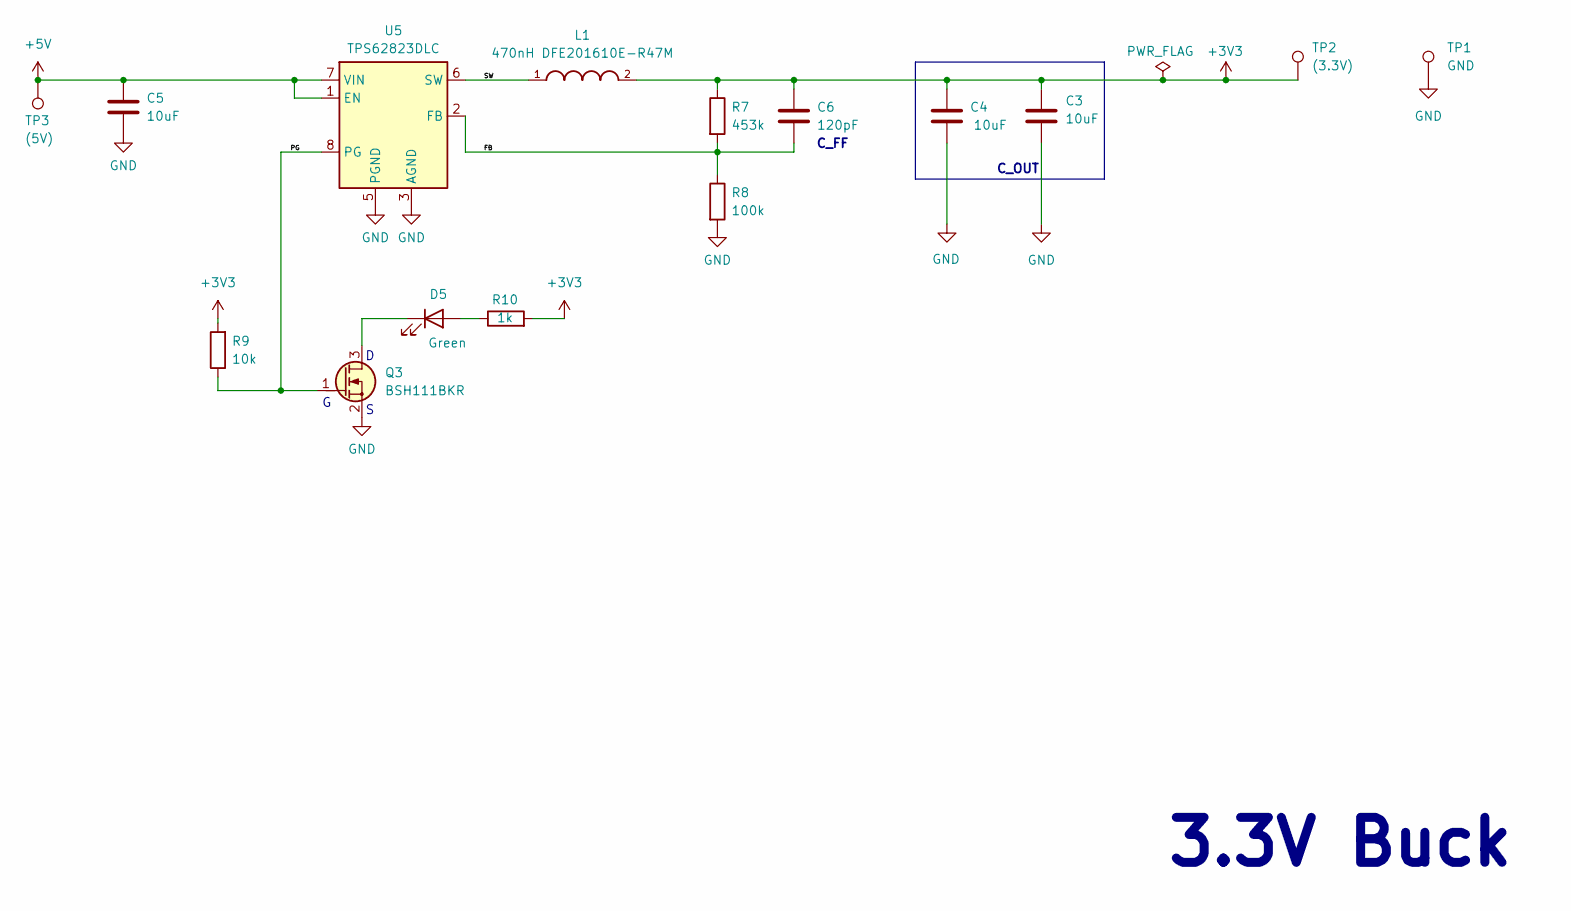
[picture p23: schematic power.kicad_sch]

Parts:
C3, C4, C5: 10uF; C_0603_1608Metric; MPN GRM188Z71A106KA73D
C6: 120pF; C_0201_0603Metric; MPN GRM033R71E121KA01D
D5: Green; LED_0603_1608Metric; MPN 150060VS75000
L1: 470nH DFE201610E-R47M; DFE201610E-R47M=P2; MPN DFE201610E-R47M=P2
Q3: BSH111BKR; SOT-23; MPN BSH111BKR
R7: 453k; R_0201_0603Metric; MPN RC0201FR-07453KL
R8: 100k; R_0201_0603Metric; MPN RC0201FR-07100KL
R9: 10k; R_0201_0603Metric; MPN RC0201FR-0710KL
R10: 1k; R_0201_0603Metric; MPN RC0201FR-071KL
TP1: GND; TestPoint_Pad_2.0x2.0mm
TP2: (3.3V); TestPoint_Pad_2.0x2.0mm
TP3: (5V); TestPoint_Pad_2.0x2.0mm
U5: TPS62823DLC; Texas_VSON-HR-8_1.5x2mm_P0.5mm; MPN TPS62823DLCT

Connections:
+3V3: C3.1, C4.1, C6.1, L1.2, R7.1, R9.2, R10.2, TP2.1; also elsewhere on the board
+5V: C5.1, TP3.1, U5.1 (EN), U5.7 (VIN); also elsewhere on the board
/Power/FB: C6.2, R7.2, R8.1, U5.2 (FB)
/Power/PG: Q3.1 (G), R9.1, U5.8 (PG)
/Power/SW: L1.1, U5.6 (SW)
GND: C3.2, C4.2, C5.2, Q3.2 (S), R8.2, TP1.1, U5.3 (AGND), U5.5 (PGND); also elsewhere on the board
unnamed: D5.2 (A), R10.1
unnamed: D5.1 (K), Q3.3 (D)

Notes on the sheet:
3.3V Buck
C_FF
C_OUT

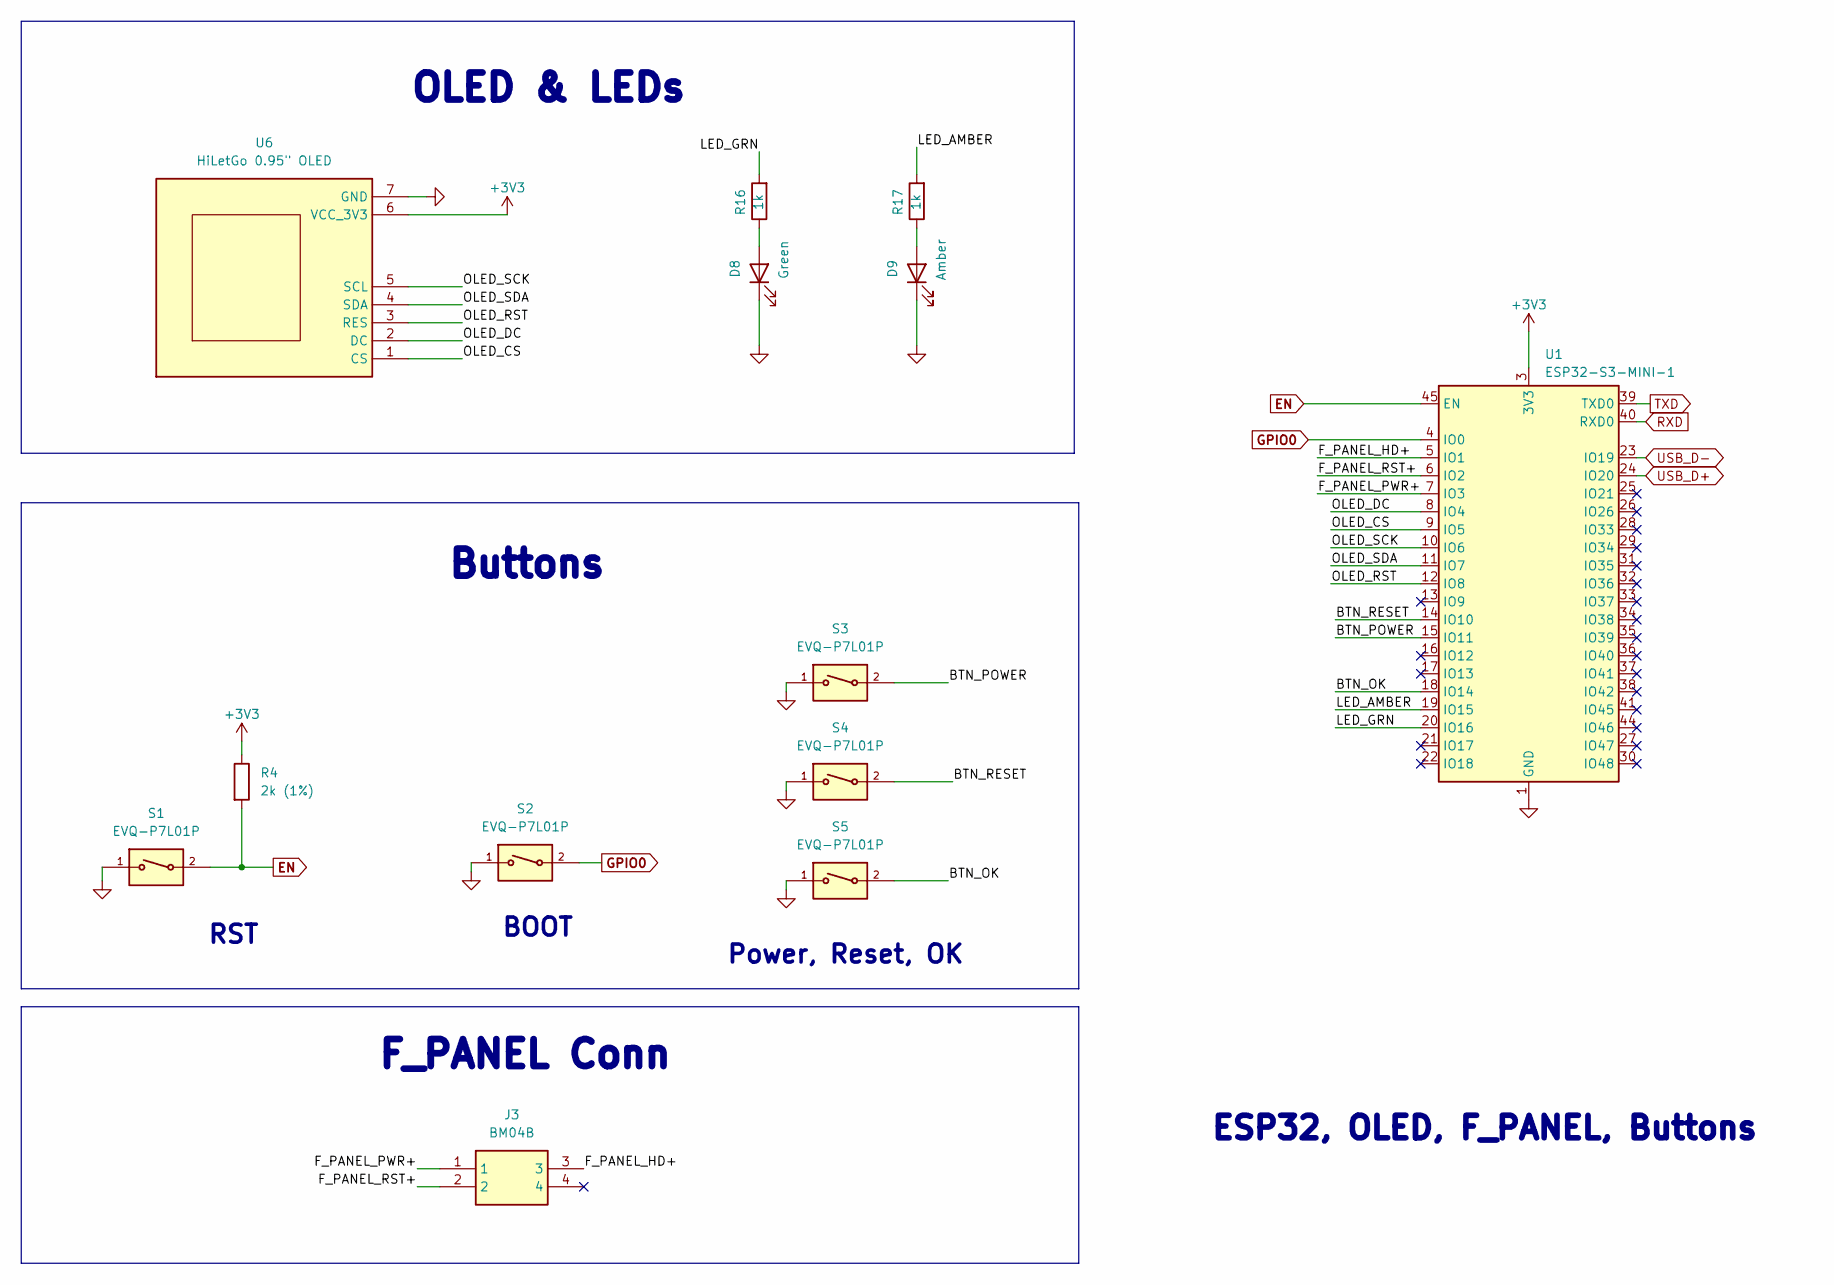
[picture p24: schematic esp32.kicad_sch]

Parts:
D8: Green; LED_0603_1608Metric; MPN 150060VS75000
D9: Amber; LED_0603_1608Metric; MPN 150060AS75000
J3: BM04B; BM04B-SRSS-TB_LFSN_; MPN BM04B-SRSS-TB(LF)(SN)
R4: 2k (1%); R_0201_0603Metric; MPN RC0201FR-072KL
R16, R17: 1k; R_0201_0603Metric; MPN RC0201FR-071KL
S1, S2, S3, S4, S5: EVQ-P7L01P; SW_EVQ-P7L01P; MPN EVQ-P7L01P
U1: ESP32-S3-MINI-1; ESP32-S2-MINI-1; MPN ESP32-S3-MINI-1-N8
U6: HiLetGo 0.95" OLED; OLED 0.95in Receptacle+Holes Only Footprint

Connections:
+3V3: R4.1, U1.3 (3V3), U6.6 (VCC_3V3); also elsewhere on the board
/ESP32/BTN_OK: S5.2, U1.18 (IO14)
/ESP32/BTN_POWER: S3.2, U1.15 (IO11)
/ESP32/BTN_RESET: S4.2, U1.14 (IO10)
/ESP32/F_PANEL_HD+: J3.3, U1.5 (IO1)
/ESP32/F_PANEL_PWR+: J3.1, U1.7 (IO3)
/ESP32/F_PANEL_RST+: J3.2, U1.6 (IO2)
/ESP32/LED_AMBER: R17.2, U1.19 (IO15)
/ESP32/LED_GRN: R16.2, U1.20 (IO16)
/ESP32/OLED_CS: U1.9 (IO5), U6.1 (CS)
/ESP32/OLED_DC: U1.8 (IO4), U6.2 (DC)
/ESP32/OLED_RST: U1.12 (IO8), U6.3 (RES)
/ESP32/OLED_SCK: U1.10 (IO6), U6.5 (SCL)
/ESP32/OLED_SDA: U1.11 (IO7), U6.4 (SDA)
EN: R4.2, S1.2, U1.45 (EN); also elsewhere on the board
GND: D8.1 (K), D9.1 (K), S1.1, S2.1, S3.1, S4.1, S5.1, U1.1 (GND), U1.2 (GND), U1.42 (GND), U1.43 (GND), U1.46 (GND), U1.47 (GND), U1.48 (GND), U1.49 (GND), U1.50 (GND), U1.51 (GND), U1.52 (GND), U1.53 (GND), U1.54 (GND), U1.55 (GND), U1.56 (GND), U1.57 (GND), U1.58 (GND), U1.59 (GND), U1.60 (GND), U1.61 (GND), U1.62 (GND), U1.63 (GND), U1.64 (GND), U1.65 (GND), U6.7 (GND); also elsewhere on the board
GPIO0: S2.2, U1.4 (IO0); also elsewhere on the board
unnamed: D8.2 (A), R16.1
unnamed: D9.2 (A), R17.1
RXD: U1.40 (RXD0); also elsewhere on the board
TXD: U1.39 (TXD0); also elsewhere on the board
USB_D+: U1.24 (IO20); also elsewhere on the board
USB_D-: U1.23 (IO19); also elsewhere on the board

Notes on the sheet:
Power, Reset, OK
RST
OLED & LEDs
Buttons
BOOT
F_PANEL Conn
ESP32, OLED, F_PANEL, Buttons

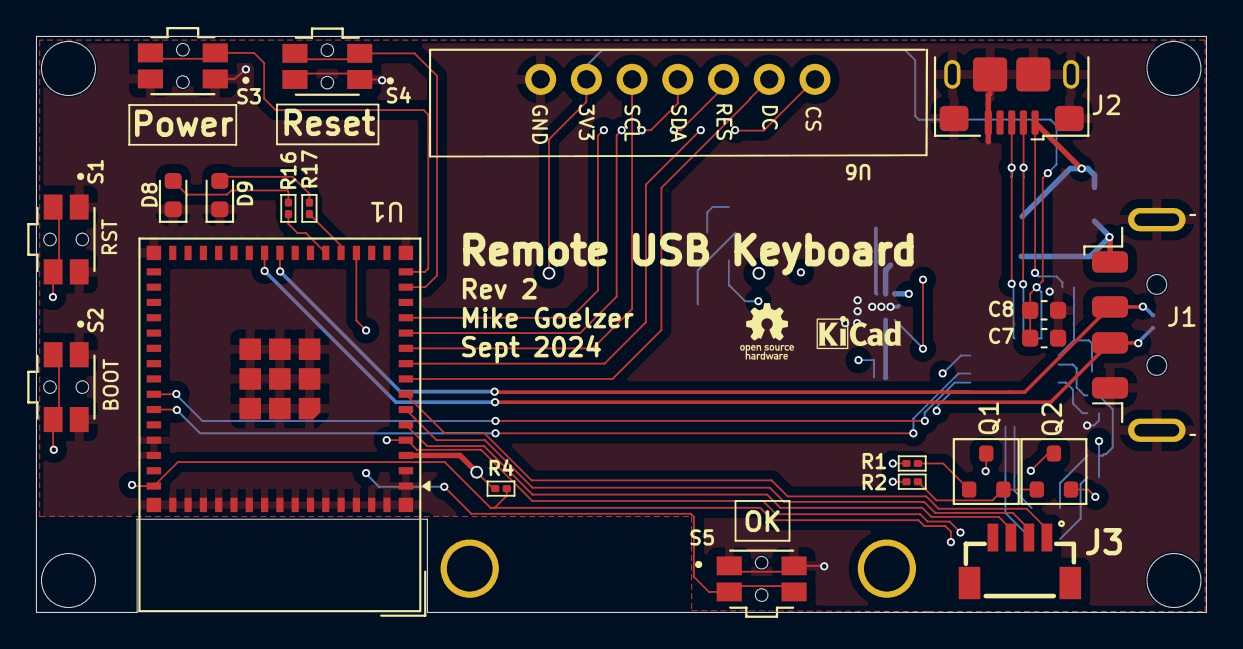
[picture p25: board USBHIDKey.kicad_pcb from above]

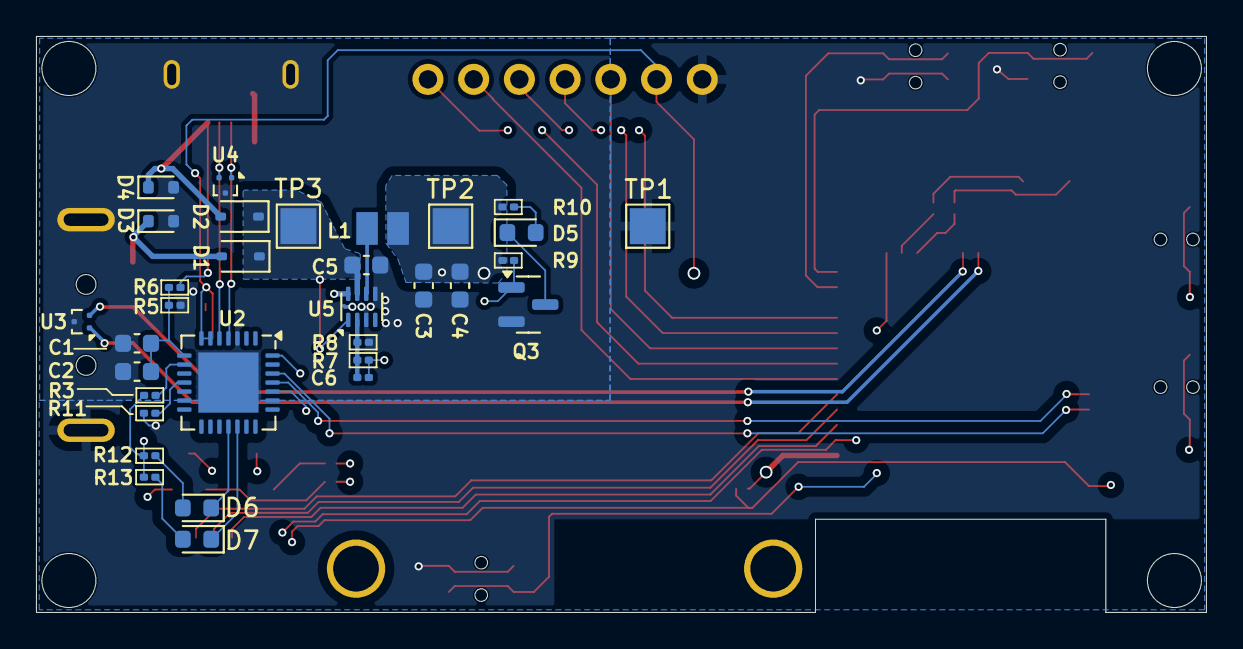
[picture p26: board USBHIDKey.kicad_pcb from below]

Board: 4 copper layers, 65.0 x 32.0 mm, 57 parts (32 on the bottom side), 44 nets.

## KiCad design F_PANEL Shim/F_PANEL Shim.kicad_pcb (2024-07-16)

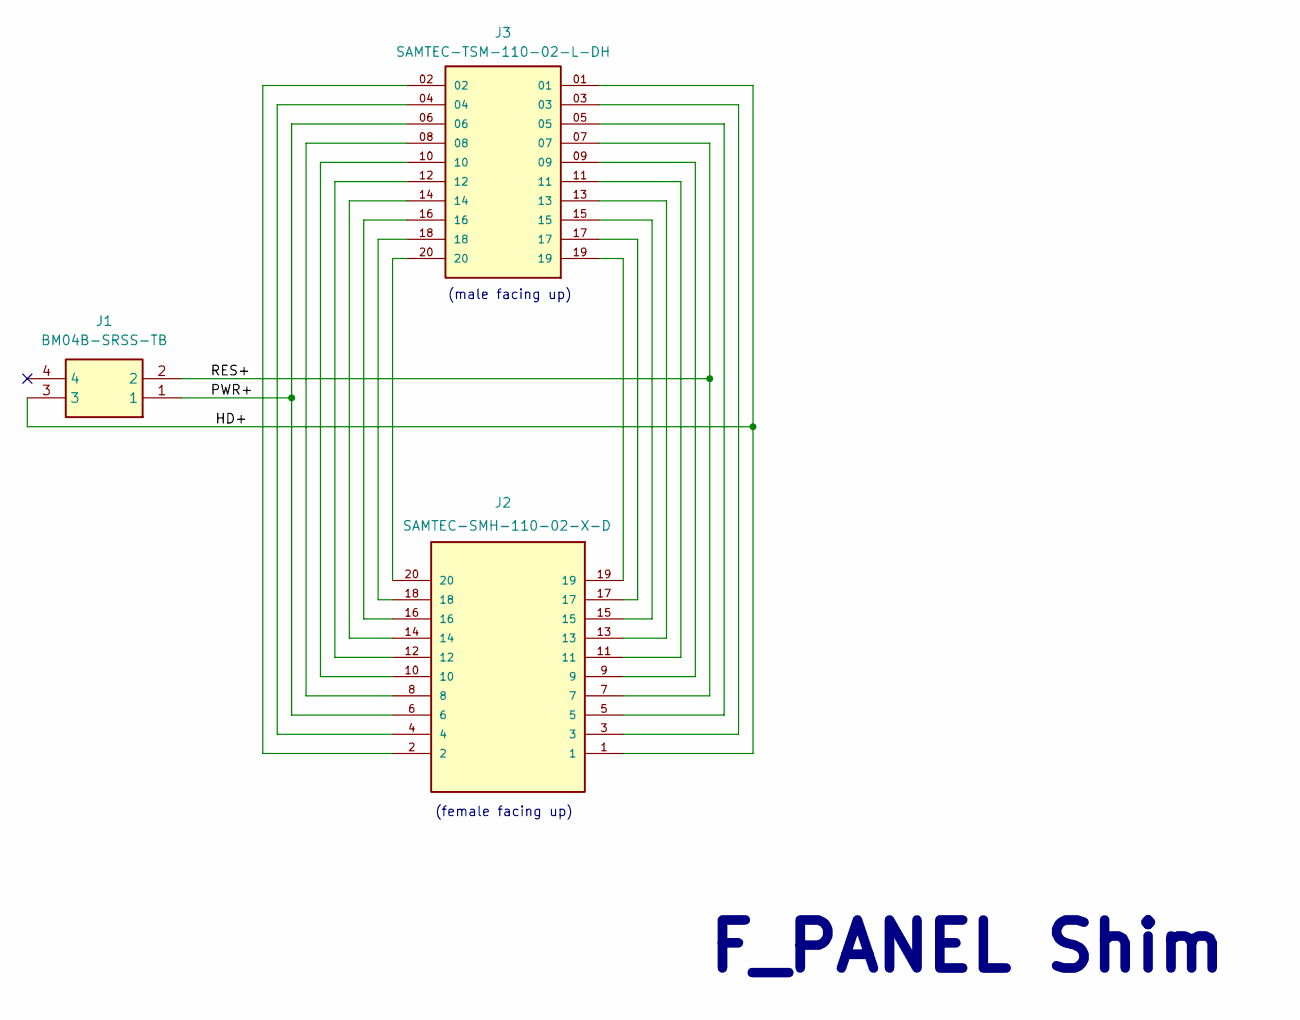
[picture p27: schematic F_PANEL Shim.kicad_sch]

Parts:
J1: BM04B-SRSS-TB; JST SH - BM04B-SRSS-TB_LFSN_; Manufacturer_Part_Number BM04B-SRSS-TB(LF)(SN)
J2: SAMTEC-SMH-110-02-X-D
J3: SAMTEC-TSM-110-02-L-DH; SAMTEC_TSM-110-02-L-DH; PARTREV R

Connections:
/HD+: J1.3, J2.1, J3.01
/PWR+: J1.1, J2.6, J3.06
/RES+: J1.2, J2.7, J3.07
unnamed: J2.2, J3.02
unnamed: J2.3, J3.03
unnamed: J2.4, J3.04
unnamed: J2.5, J3.05
unnamed: J2.8, J3.08
unnamed: J2.9, J3.09
unnamed: J2.10, J3.10
unnamed: J2.11, J3.11
unnamed: J2.12, J3.12
unnamed: J2.13, J3.13
unnamed: J2.14, J3.14
unnamed: J2.15, J3.15
unnamed: J2.16, J3.16
unnamed: J2.17, J3.17
unnamed: J2.18, J3.18
unnamed: J2.19, J3.19
unnamed: J2.20, J3.20

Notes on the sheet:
F_PANEL Shim
(male facing up)
(female facing up)

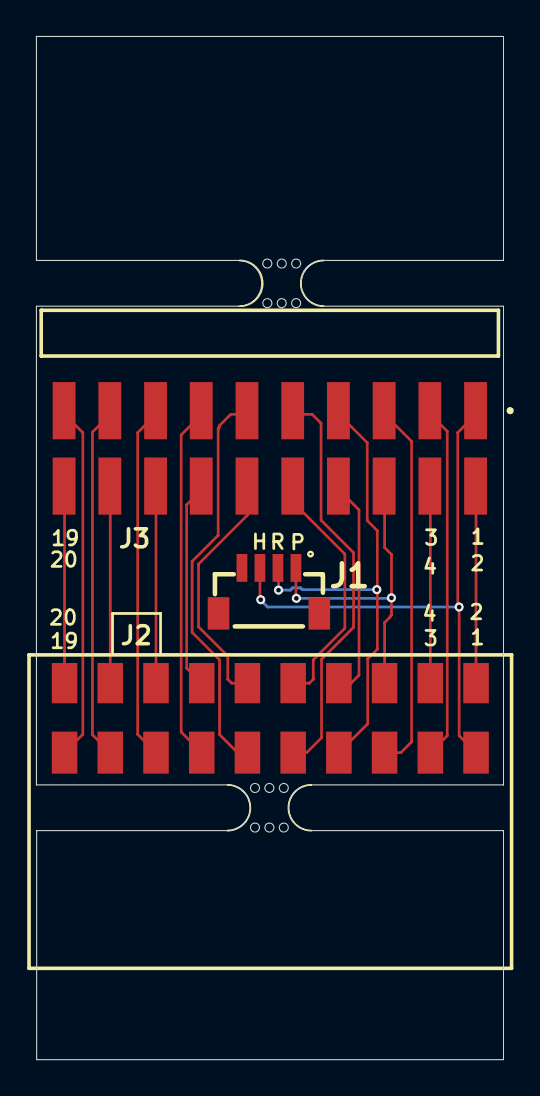
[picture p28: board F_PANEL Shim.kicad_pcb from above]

Board: 2 copper layers, 25.9 x 56.8 mm, 5 parts (0 on the bottom side), 20 nets.

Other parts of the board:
mouse-bite-2.54mm-slot, mouse-bite-2.54mm-slot#2: VAL**; mouse-bite-2.54mm-slot

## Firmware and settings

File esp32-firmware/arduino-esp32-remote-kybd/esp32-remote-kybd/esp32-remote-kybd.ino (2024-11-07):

/*

-----
SETUP
-----
  - Serial monitor: 115200 baud

------
TO RUN
------
  - Plug in both USB ports at the same time (no button held)

----------------
TO PROGRAM BOARD
----------------

  - Select board in top bar drop-down: "ESP32-S3-USB-OTG"
  - Plug in both USB ports to host PC
  - Press Upload arrow
  - Wait...
  - After "Hard resetting via RTS pin..." press the RESET button on board

If not having luck, this try instead:
  - Start with board unplugged
  - Hold down BOOT button while plugging in debug port USB
  - Release BOOT button
  - Press Upload arrow

*/

// this whole ifndef...elif...else can probably be eliminated as we are USB device-only not OTG
#define ARDUINO_USB_MODE 0
#ifndef ARDUINO_USB_MODE
#error This ESP32 SoC has no Native USB interface
#elif ARDUINO_USB_MODE == 1
#warning This sketch should be used when USB is in OTG mode
void setup() {}
void loop() {}
#else

#include "USB.h"
#include "USBHIDKeyboard.h"
USBHIDKeyboard Keyboard;
#include <WiFi.h>
#include "secrets.h"  // add WLAN Credentials in here
#include <Arduino.h>
#include <WebServer.h>

// GPIO pins
#define LED_AMBER           15
#define LED_GREEN           16
#define USER_BTN_OK         14
#define USER_BTN_POWER      11
#define USER_BTN_RESET      10
#define FPANEL_HDD_ACTIVITY 1
#define FPANEL_MOBO_RESET   2
#define FPANEL_MOBO_POWER   3

////////////////////////////////////////////////////////////
//
// hid keyboard functions
//
////////////////////////////////////////////////////////////

void kybd_do_login() {
    // Goal is to type "<ENTER>$PASSWORD<ENTER>"
    Keyboard.press(KEY_RETURN);       // press ENTER
    Keyboard.releaseAll();            // release ENTER
    delay(250);
    Keyboard.print(LOGIN_PASSWORD);
    Keyboard.press(KEY_RETURN);       // press ENTER
    Keyboard.releaseAll();            // release ENTER
}

void kybd_do_confirm_logout() {
    // Goal is to type "<right arrow><ENTER>"
    Keyboard.press(KEY_RIGHT_ARROW);  // arrow right
    Keyboard.releaseAll();            // release arrow
    Keyboard.press(KEY_RETURN);       // press ENTER
    Keyboard.releaseAll();            // release ENTER
}

////////////////////////////////////////////////////////////
//
// state machine
//
////////////////////////////////////////////////////////////

enum state_t {
  STATE_UNINITIALIZED,      // LEDs: off
  STATE_MOBO_OFF,           // LEDs: solid amber
  STATE_MOBO_POWERING_UP,   // LEDs: blinking green
  STATE_MOBO_POWERING_DOWN, // LEDs: blinking amber
  STATE_MOBO_ON             // LEDs: solid green
};
volatile state_t state = STATE_UNINITIALIZED;
volatile unsigned long last_saw_hdd_activity_high = 0;
#define MAX_EXPECTED_TIME_ON_WITHOUT_HDD_ACTIVITY_MILLIS 100
#define POWERING_ON_DELAY_TO_LOGIN_MS ((30+28)*1000)
#define POWERING_OFF_DELAY_TO_LOGOUT_MS (3*1000)
#define POWERING_OFF_DELAY_TO_OFF_STATE_MS ((POWERING_OFF_DELAY_TO_LOGOUT_MS)+(3*1000))
volatile unsigned long powering_state_since = 0;
volatile bool reset_requested = false;
volatile bool power_signal_requested = false;
volatile bool login_keystrokes_requested = false;
volatile bool logout_keystrokes_requested = false;
volatile bool logout_keystrokes_sent = false;

void send_power_signal_to_mobo() {
  digitalWrite(FPANEL_MOBO_POWER, LOW);
  delay(100);
  digitalWrite(FPANEL_MOBO_POWER, HIGH);
}

void send_reset_signal_to_mobo() {
  digitalWrite(FPANEL_MOBO_RESET, LOW);
  delay(100);
  digitalWrite(FPANEL_MOBO_RESET, HIGH);
}

void transition_to_powering_up() {
  // do not use Serial.print; may be called from an ISR

  // update state vars
  state = STATE_MOBO_POWERING_UP;
  powering_state_since = millis();
}

void transition_to_powering_down() {
  // do not use Serial.print; may be called from an ISR

  // update state vars
  state = STATE_MOBO_POWERING_DOWN;
  powering_state_since = millis();
  logout_keystrokes_sent = false;
  logout_keystrokes_requested = false;
}

void dbg_print_state(const char *caller = NULL) {
  String state_str;
  switch (state) {
    case STATE_MOBO_OFF:
      state_str = "STATE_MOBO_OFF";
      break;
    case STATE_MOBO_POWERING_UP:
      state_str = "STATE_MOBO_POWERING_UP";
      break;
    case STATE_MOBO_ON:
      state_str = "STATE_MOBO_ON";
      break;
    case STATE_MOBO_POWERING_DOWN:
      state_str = "STATE_MOBO_POWERING_DOWN";
      break;
    case STATE_UNINITIALIZED:
      state_str = "STATE_UNINITIALIZED";
      break;
    default:
      state_str = "UNKNOWN";
      break;
  }
  Serial.printf("state: %s", state_str.c_str());
  if (caller != NULL)
    Serial.printf(" (caller: %s)\n", caller);
  else
    Serial.printf("\n");
}

void fsm() {
  switch (state) {
    case STATE_MOBO_OFF:
      // LEDs: solid amber
      digitalWrite(LED_AMBER, HIGH);
      digitalWrite(LED_GREEN, LOW);

      // sense HDD activity: if it's on, we should be in ON state instead
      if (digitalRead(FPANEL_HDD_ACTIVITY) == HIGH) {
        state = STATE_MOBO_ON;
        dbg_print_state();
      }
      break;

    case STATE_MOBO_POWERING_UP:
      // LEDs: blinking green
      digitalWrite(LED_AMBER, LOW);
      if (millis() % 50 < 25)
        digitalWrite(LED_GREEN, HIGH);
      else
        digitalWrite(LED_GREEN, LOW);

      // after appropriate delay, send login sequence
      if (millis() - powering_state_since > POWERING_ON_DELAY_TO_LOGIN_MS) {
        login_keystrokes_requested = true;
        state = STATE_MOBO_ON;
        dbg_print_state();
      }
      break;
    
    case STATE_MOBO_POWERING_DOWN:
      // LEDs: blinking amber
      digitalWrite(LED_GREEN, LOW);
      if (millis() % 50 < 25)
        digitalWrite(LED_AMBER, HIGH);
      else
        digitalWrite(LED_AMBER, LOW);

      // after appropriate delay, send logout confirm sequence
      if ((millis() - powering_state_since > POWERING_OFF_DELAY_TO_LOGOUT_MS) && (!logout_keystrokes_sent)) {
        logout_keystrokes_requested = true;
        dbg_print_state();
      }
      if ((millis() - powering_state_since > POWERING_OFF_DELAY_TO_OFF_STATE_MS)) {
        state = STATE_MOBO_OFF;
        dbg_print_state();
      }
      break;

    case STATE_MOBO_ON:
      // LEDs: solid green
      digitalWrite(LED_GREEN, HIGH);
      digitalWrite(LED_AMBER, LOW);

      // sense HDD activity: if it's off for long enough, we should be in OFF state instead
      if (digitalRead(FPANEL_HDD_ACTIVITY) == LOW && (millis() - last_saw_hdd_activity_high > MAX_EXPECTED_TIME_ON_WITHOUT_HDD_ACTIVITY_MILLIS)) {
        state = STATE_MOBO_OFF;
        dbg_print_state();
      }
      break;

    case STATE_UNINITIALIZED:
    default:
      // LEDs: off
      digitalWrite(LED_GREEN, LOW);
      digitalWrite(LED_AMBER, LOW);

      // sense HDD activity and go to either mobo on or mobo off state
      if (digitalRead(FPANEL_HDD_ACTIVITY) == LOW) {
        state = STATE_MOBO_OFF;
        dbg_print_state();
      } else {
        state = STATE_MOBO_ON;
        dbg_print_state();
      }
      break;
  }
}

////////////////////////////////////////////////////////////
//
// ISRs for button presses
//
////////////////////////////////////////////////////////////

volatile unsigned long lastOkPressTime = 0;
volatile unsigned long lastPowerPressTime = 0;
volatile unsigned long lastResetPressTime = 0;
const unsigned long BTN_DEBOUNCE_MS = 50;
volatile unsigned long btnInterruptsEnabled = 0; // start with buttons disabled

void IRAM_ATTR okButtonISR() {
  if (btnInterruptsEnabled == 0)
    return;

  // debounce
  unsigned long now = millis();
  if (now - lastOkPressTime >= BTN_DEBOUNCE_MS) {
    lastOkPressTime = now;

    // code to handle OK button press
    // ...(button does nothing, just here for future use)...
  }
}

void IRAM_ATTR powerButtonISR() {
  if (btnInterruptsEnabled == 0) {
    return;
  }

  // debounce
  unsigned long now = millis();
  if (now - lastPowerPressTime >= BTN_DEBOUNCE_MS) {
    lastPowerPressTime = now;

    // code to handle POWER button press
    switch(state) {
      case STATE_MOBO_OFF:
        // send signal and transition to powering up state
        power_signal_requested = true;
        transition_to_powering_up();
        break;
      case STATE_MOBO_ON:
        // send signal and transition to off state
        power_signal_requested = true;
        transition_to_powering_down();
        break;
      case STATE_MOBO_POWERING_UP:
      case STATE_MOBO_POWERING_DOWN:
      case STATE_UNINITIALIZED:
        // no-op if already in a powering state or uninitialized
        break;
    }
  }
  //dbg_print_state("powerButtonISR");
}

void IRAM_ATTR resetButtonISR() {
  if (btnInterruptsEnabled == 0) {
    return;
  }

  // debounce
  unsigned long now = millis();
  if (now - lastResetPressTime >= BTN_DEBOUNCE_MS) {
    lastResetPressTime = now;

    // when resetting from off state, send power signal instead of reset signal
    if (state == STATE_MOBO_OFF) {
      power_signal_requested = true;
    } else {
      reset_requested = true;
    }

    transition_to_powering_up();
  }
}

////////////////////////////////////////////////////////////
//
// WiFi
//
////////////////////////////////////////////////////////////

void connectToWiFi() {
  Serial.println();
  Serial.println("******************************************************");
  Serial.print("Connecting to ");
  Serial.println(ssid);

  WiFi.begin(ssid, password);
  while (WiFi.status() != WL_CONNECTED) {
    delay(500);
    Serial.print(".");
  }
  Serial.println("");
  Serial.println("WiFi connected");
  Serial.println("IP address: ");
  Serial.println(WiFi.localIP());
}

////////////////////////////////////////////////////////////
//
// webserver
//
////////////////////////////////////////////////////////////

// TRACE output simplified, can be deactivated here
#define TRACE(...) Serial.printf(__VA_ARGS__)

// name of the server. You reach it using http://webserver
#define HOSTNAME "webserver"

// local time zone definition (U.S. Mountain Time)
#define TIMEZONE "MST7MDT,M3.2.0,M11.1.0"

WebServer server(52000);

// return string with HDD activity status string
String getHddActivityString() {
  return "hdd: " + String(digitalRead(FPANEL_HDD_ACTIVITY)) + " (last HIGH: " + String(millis() - last_saw_hdd_activity_high) + "ms ago)";
}

// return string with current state
String getStateString() {
  String result;
  switch (state) {
    case STATE_MOBO_OFF:
      result = "state: STATE_MOBO_OFF\n" + getHddActivityString() + ")";
      break;
    case STATE_MOBO_POWERING_UP:
      result = "state: STATE_MOBO_POWERING_UP\n" + getHddActivityString();
      break;
    case STATE_MOBO_ON:
      result = "state: STATE_MOBO_ON\n" + getHddActivityString();
      break;
    case STATE_MOBO_POWERING_DOWN:
      result = "state: STATE_MOBO_POWERING_DOWN\n" + getHddActivityString();
      break;
    case STATE_UNINITIALIZED:
      result = "state: STATE_UNINITIALIZED\n" + getHddActivityString();
      break;
    default:
      result = "state: (unknown)\n" + getHddActivityString();
      break;
  }
  return result;
}

// endpoint: /
void handleRoot() {
  String result;
  Serial.println();
  Serial.println("******************************************************");
  Serial.println("GET /");
  result += getStateString();
  result += "\n\n";
  result += "endpoints:\n";
  result += "  /                 (this page)\n";
  result += "  /info             system info\n";
  result += "  /on               power on (no-op if already powering up or in progress)\n";
  result += "  /off              power off (no-op if already powering down or in progress)\n";
  result += "  /reset            reset\n";
  result += "\n";
  Serial.printf("responding with list of endpoints\n");
  server.sendHeader("Cache-Control", "no-cache");
  server.send(200, "text/javascript; charset=utf-8", result);
}

// endpoint: /info
void handleInfo() {
  String result;
  Serial.println();
  Serial.println("******************************************************");
  Serial.println("GET /info");
  result += "{\n";
  result += "  \"Chip Model\": " + String(ESP.getChipModel()) + ",\n";
  result += "  \"Chip Cores\": " + String(ESP.getChipCores()) + ",\n";
  result += "  \"Chip Revision\": " + String(ESP.getChipRevision()) + ",\n";
  result += "  \"flashSize\": " + String(ESP.getFlashChipSize()) + ",\n";
  result += "  \"freeHeap\": " + String(ESP.getFreeHeap()) + ",\n";
  result += "}\n";
  result += getStateString();
  result += "\n\n";
  Serial.printf("responding with system info\n");
  server.sendHeader("Cache-Control", "no-cache");
  server.send(200, "text/javascript; charset=utf-8", result);
}

// endpoint: /on
void handleOn() {
  String result = "OK";

  // update state
  switch (state) {
    case STATE_MOBO_OFF:
      power_signal_requested = true;
      transition_to_powering_up();
      result = "handleOn(): going to STATE_MOBO_POWERING_UP";
      break;
    case STATE_MOBO_ON:
      result = "handleOn(): no-op (already in STATE_MOBO_ON)";
      break;
    case STATE_MOBO_POWERING_UP:
      result = "handleOn(): no-op (already in STATE_MOBO_POWERING_UP for " + String(millis() - powering_state_since) + "ms)";
      break;
    case STATE_MOBO_POWERING_DOWN:
      result = "handleOff(): no-op (in STATE_MOBO_POWERING_DOWN for " + String(millis() - powering_state_since) + "ms)";
      break;
    case STATE_UNINITIALIZED:
      result = "handleOn(): no-op (in STATE_UNINITIALIZED)";
      break;
    default:
      result = "state: (unknown)";
      break;
  }

  Serial.println();
  Serial.println("******************************************************");
  Serial.println("GET /on");
  Serial.printf("responding: '%s'\n", result.c_str());
  server.sendHeader("Cache-Control", "no-cache");
  server.send(200, "text/javascript; charset=utf-8", result);
}

// endpoint: /off
void handleOff() {
  String result = "OK";

  // update state
  switch (state) {
    case STATE_MOBO_OFF:
      result = "handleOff(): no-op (already in STATE_MOBO_OFF)";
      break;
    case STATE_MOBO_ON:
      power_signal_requested = true;
      transition_to_powering_down();
      result = "handleOff(): going to STATE_MOBO_POWERING_DOWN";
      break;
    case STATE_MOBO_POWERING_UP:
      result = "handleOff(): no-op (in STATE_MOBO_POWERING_UP for " + String(millis() - powering_state_since) + "ms)";
      break;
    case STATE_MOBO_POWERING_DOWN:
      result = "handleOff(): no-op (already in STATE_MOBO_POWERING_DOWN for " + String(millis() - powering_state_since) + "ms)";
      break;
    default:
    case STATE_UNINITIALIZED:
      result = "handleOff(): no-op (in STATE_UNINITIALIZED)";
      break;
  }

  Serial.println();
  Serial.println("******************************************************");
  Serial.println("GET /off");
  Serial.printf("responding: '%s'\n", result.c_str());
  server.sendHeader("Cache-Control", "no-cache");
  server.send(200, "text/javascript; charset=utf-8", result);
}

// endpoint: /reset
void handleReset() {
  String result = "OK";

  // reset motherboard

  // send a power signal instead of reset if motherboard is off
  if (state == STATE_MOBO_OFF) {
    Serial.printf("handleReset(): setting power_signal_requested flag\n");
    power_signal_requested = true;
  } else {
    Serial.printf("handleReset(): setting reset_requested flag\n");
    reset_requested = true;
  }

  transition_to_powering_up();

  Serial.println();
  Serial.println("******************************************************");
  Serial.println("GET /reset");
  Serial.printf("responding: '%s'\n", result.c_str());
  server.sendHeader("Cache-Control", "no-cache");
  server.send(200, "text/javascript; charset=utf-8", result);
}

// endpoint: /login
void handleLogin() {
  String result = "OK";

  // set flag to send login keystrokes
  login_keystrokes_requested = true;
  Serial.printf("handleLogin(): setting login_keystrokes_requested flag\n");

  Serial.println();
  Serial.println("******************************************************");
  Serial.println("GET /login");
  Serial.printf("responding: '%s'\n", result.c_str());
  server.sendHeader("Cache-Control", "no-cache");
  server.send(200, "text/javascript; charset=utf-8", result);
}

void registerHttpHandlers() {
  server.on("/", HTTP_GET, handleRoot);
  server.on("/info", HTTP_GET, handleInfo);
  server.on("/on", HTTP_GET, handleOn);
  server.on("/off", HTTP_GET, handleOff);
  server.on("/reset", HTTP_GET, handleReset);
  server.on("/login", HTTP_GET, handleLogin);
}

////////////////////////////////////////////////////////////
//
// setup() and loop()
//
////////////////////////////////////////////////////////////

void setup() {
  // open the serial port
  Serial.begin(115200);

  // initialize control over the keyboard:
  Keyboard.begin();
  USB.begin();

  // initialize GPIO pins
  pinMode(LED_AMBER, OUTPUT);
  pinMode(LED_GREEN, OUTPUT);
  pinMode(USER_BTN_OK, INPUT_PULLUP);
  pinMode(USER_BTN_POWER, INPUT_PULLUP);
  pinMode(USER_BTN_RESET, INPUT_PULLUP);
  attachInterrupt(digitalPinToInterrupt(USER_BTN_OK), okButtonISR, FALLING);
  attachInterrupt(digitalPinToInterrupt(USER_BTN_POWER), powerButtonISR, FALLING);
  attachInterrupt(digitalPinToInterrupt(USER_BTN_RESET), resetButtonISR, FALLING);
  pinMode(FPANEL_MOBO_POWER, OUTPUT); 
  pinMode(FPANEL_MOBO_RESET, OUTPUT);
  digitalWrite(FPANEL_MOBO_POWER, HIGH);
  digitalWrite(FPANEL_MOBO_RESET, HIGH);
  pinMode(FPANEL_HDD_ACTIVITY, INPUT);

  // connect to WiFi
  connectToWiFi();

  // start webserver
  server.begin();

  // get current time
  Serial.println();
  Serial.println("******************************************************");
  Serial.println("setting up ntp");
  configTzTime(TIMEZONE, "pool.ntp.org");

  Serial.println();
  Serial.println("******************************************************");
  Serial.println("registering http handlers");
  registerHttpHandlers();


  // clear all flags
  reset_requested = false;
  power_signal_requested = false;
  login_keystrokes_requested = false;
  logout_keystrokes_requested = false;
  logout_keystrokes_sent = false;

  // start state and enable interrupts
  state = STATE_UNINITIALIZED;
  btnInterruptsEnabled = 1;
}

void loop() {
  // keep track of last time HDD activity input was HIGH (used by FSM)
  if (digitalRead(FPANEL_HDD_ACTIVITY) == HIGH)
    last_saw_hdd_activity_high = millis();

  // state machine on every loop iteration
  fsm();

  // handle webserver
  server.handleClient();

  // handle power and reset requests
  if (reset_requested) {
    reset_requested = false;
    send_reset_signal_to_mobo();
    Serial.printf("loop(): handled reset request and cleared reset_requested flag\n");
  }
  if (power_signal_requested) {
    power_signal_requested = false;
    send_power_signal_to_mobo();
    Serial.printf("loop(): handled power signal request and cleared power_signal_requested flag\n");
  }

  // send login keystrokes if requested
  if (login_keystrokes_requested) {
    login_keystrokes_requested = false;
    kybd_do_login();
    Serial.printf("loop(): handled login keystrokes request and cleared login_keystrokes_requested flag\n");
  }
  if (logout_keystrokes_requested) {
    logout_keystrokes_requested = false;
    logout_keystrokes_sent = true;
    kybd_do_confirm_logout();
    Serial.printf("loop(): handled logout keystrokes request and cleared logout_keystrokes_requested flag\n");
  }
}
#endif /* ARDUINO_USB_MODE */

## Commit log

2024-07-16 relocate esp32 firmware
2024-07-16 silkscreen images and readme
2024-07-16 add silkscreen images in kicad
    [USBHIDKey.kicad_pcb]
2024-07-16 script for bulk modify pcb parts
2024-07-16 fix 3d models for some parts
    [USBHIDKey.kicad_pcb]
2024-07-16 silkscreen fix
    [USBHIDKey.kicad_pcb]
2024-07-23 updates for PCBWay assembly order
    [PCBWay-BOM.xlsx, PartsOrder.xlsx, T-2C2W538179A-2sets-PCBWay-BOM(2024-07-18) - CORRECTED.xls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]
2024-09-08 get kicad auto-backup files out of git's index
2024-09-08 feedback resistor calcs for tps62283
    [tps62823 calcs.xls]
2024-09-08 BOM changes: moved original to rev1 dir; started new BOM in rev2 dir
    [PCBWay-BOM.xlsx, T-2C2W538179A-2sets-PCBWay-BOM(2024-07-18) - CORRECTED.xls]
2024-09-08 renamed rev2 bom for clarity
    [PCBWay-BOM-Rev2.xlsx]
2024-09-08 fix excel extension so file opens in Excel
    [PCBWay-BOM-Rev2.xls, PCBWay-BOM-Rev2.xlsx]
2024-09-08 fixes #5
    [PCBWay-BOM-Rev2.xls]
2024-09-08 remove useless DNP rows from bom
    [PCBWay-BOM-Rev2.xls]
2024-09-08 change TX/RX LED resistors to 330
    [PCBWay-BOM-Rev2.xls, usb-uart.kicad_sch]
2024-09-08 correct R12/R13 pads to 0603 on pcd; fix ERC errors relating to Kicad library update
    [USBHIDKey-B_Cu.gbr, USBHIDKey-B_Mask.gbr, USBHIDKey-B_Paste.gbr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]
2024-09-08 swap values of R7/R8 to fix buck Vout
    [USBHIDKey.kicad_pcb, power.kicad_sch]
2024-09-08 swap R7/R8 resistor values in BOM
    [PCBWay-BOM-Rev2.xls]
2024-09-08 correct D6/D7 on BOM since now correct on pcb
    [PCBWay-BOM-Rev2.xls]
2024-09-08 specify exact resistor part numbers in BOM xls
    [PCBWay-BOM-Rev2.xls]
2024-09-08 regenerate gerbers
    [USBHIDKey-B_Cu.gbr, USBHIDKey-B_Mask.gbr, USBHIDKey-B_Paste.gbr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]
2024-09-08 update silk to 'rev 2'
    [USBHIDKey.kicad_pcb]
2024-10-30 update instructions for ESP32-S3
2024-11-07 replace with Arduino version of firmware
    [esp32-remote-kybd.ino]

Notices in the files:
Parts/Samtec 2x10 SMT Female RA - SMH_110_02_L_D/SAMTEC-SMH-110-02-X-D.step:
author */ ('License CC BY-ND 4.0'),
